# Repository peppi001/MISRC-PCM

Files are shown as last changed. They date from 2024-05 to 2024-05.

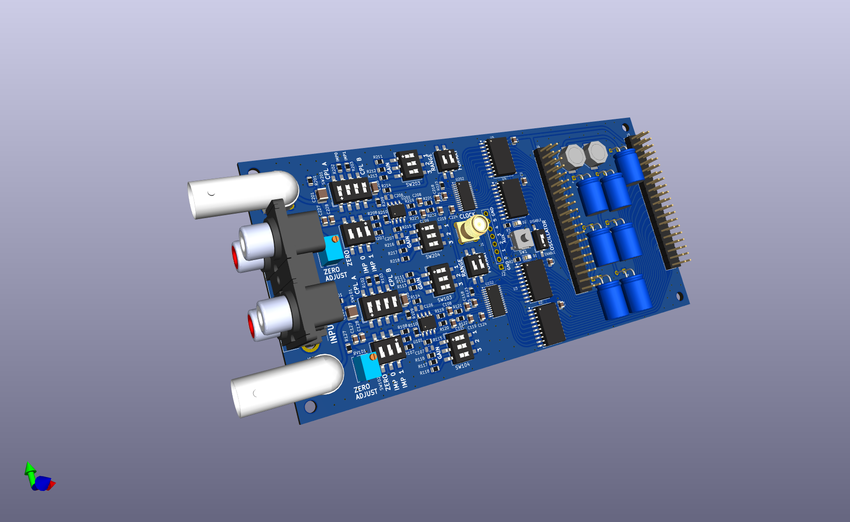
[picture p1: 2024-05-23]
3D_Pics/MISRC_v2.1_BNC_Top.png

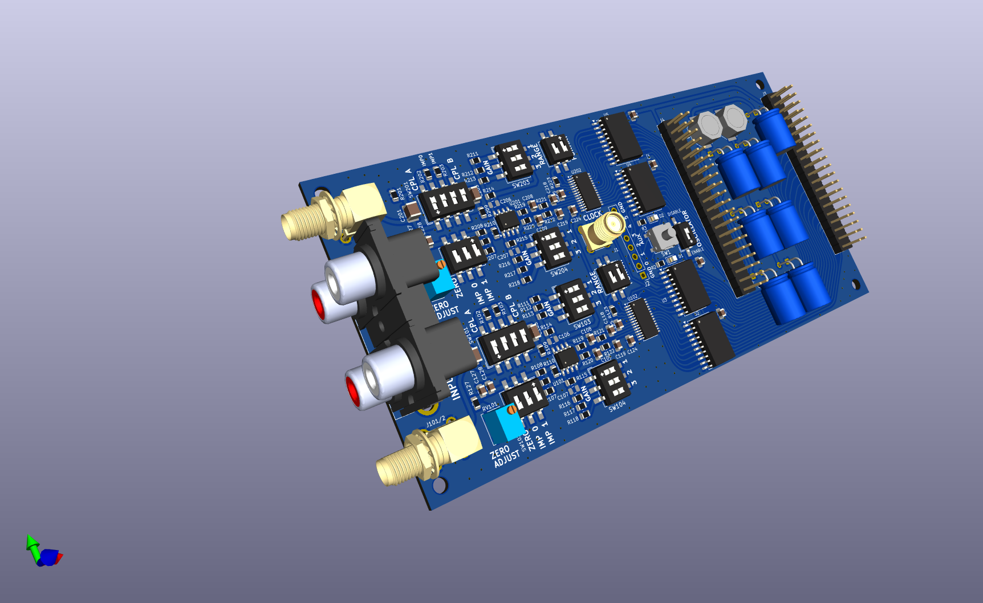
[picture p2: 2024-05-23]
3D_Pics/MISRC_v2.1_SMA_TOP.png

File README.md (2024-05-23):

# MISRC-PCM
SMA Version
MISRC_v2 1_SMA_TOP
MISRC_v2 1_SMA_BOT

BNC Version
MISRC_v2 1_BNC_Top
MISRC_v2 1_BNC_BOT

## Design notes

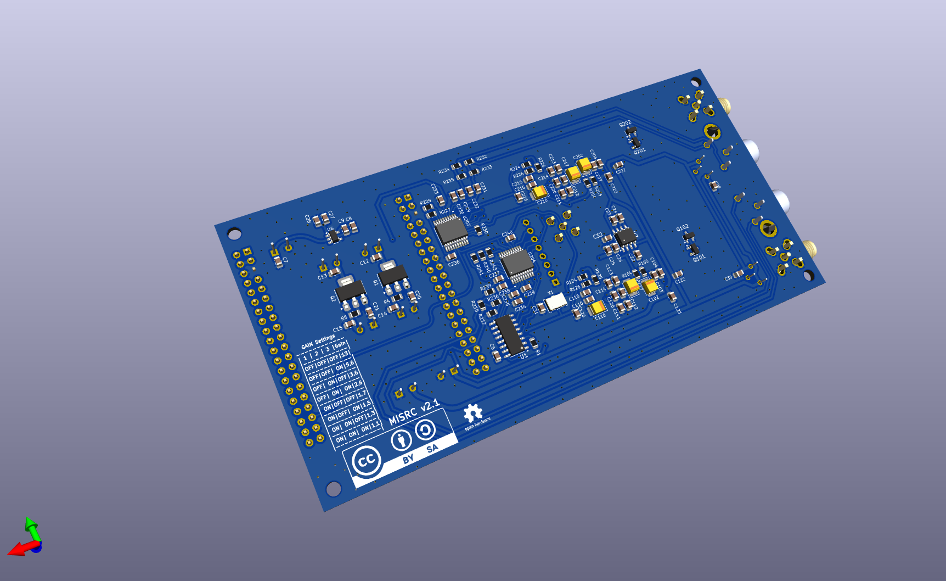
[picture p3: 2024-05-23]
3D_Pics/MISRC_v2.1_SMA_BOT.png

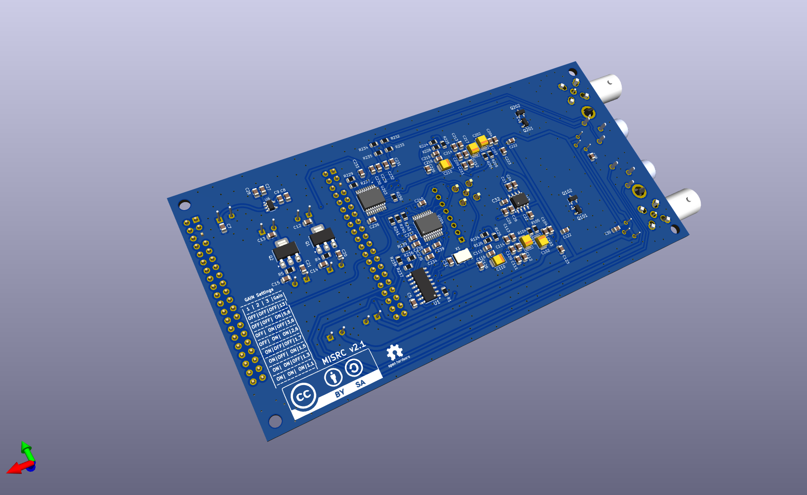
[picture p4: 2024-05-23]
3D_Pics/MISRC_v2.1_BNC_BOT.png

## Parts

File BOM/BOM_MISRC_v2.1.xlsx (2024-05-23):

Reference | Value | Footprint | Qty | DNP | Manufacturer_Part_Number
C1,C2,C3,C4,C5,C7,C12,C13,C20,C21,C22,C23,C24,C29,C30,C31,C231,C232,C237,C238 | 1u | Capacitor_SMD:C_0805_2012Metric | 20 |  | GRM219R61H105KA73D
C6,C10,C11,C16,C17,C18,C19 | 470u | CP_Radial_Flat_D8.0mm_P3.50mm | 7 |  | UHV1C471MPD
C8,C25,C28,C32,C127,C227,C229,C234 | 10u | Capacitor_SMD:C_0805_2012Metric | 8 |  | GRM21BR61C106KE15K
C9,C14,C15,C26,C103,C112,C113,C115,C120,C122,C123,C124,C125,C126,C203,C212,C213,C215,C220,C222,C223,C224,C225,C226,C230,C233,C235,C236,C239,C240 | 100n | Capacitor_SMD:C_0805_2012Metric | 30 |  | GRM21BR72A104KAC4L
C27,C104,C111,C114,C116,C121,C128,C204,C211,C214,C216,C221,C228 | 1n/1 | Capacitor_SMD:C_0805_2012Metric | 13 |  | GRM2195C1H102JA01D
C101,C201 | 100u | Capacitor_SMD:C_1210_3225Metric | 2 |  | GRM32ER61A107ME20K
C102,C110,C117,C202,C210,C217 | 10u | Capacitor_Tantalum_SMD:CP_EIA-3528-21_Kemet-B_Pad1.50x2.35mm_HandSolder | 6 |  | T491B106K016AT7280
C105,C205 | 470n/1 | Capacitor_SMD:C_1206_3216Metric | 2 |  | GRM31C5C1E474JE01L
~~C106,C107,C206,C207~~ | ~~1p~~ | ~~Capacitor_SMD:C_0805_2012Metric~~ | ~~4~~ | ~~DNP~~
C108,C109,C208,C209 | 82pF/1 | Capacitor_SMD:C_0805_2012Metric | 4 |  | GRM21A5C2D820JW01D
C118,C119,C218,C219 | 15pF/1 | Capacitor_SMD:C_0805_2012Metric | 4 |  | GRM21A5C2D150JW01D
D1,D2 | LED | LED_SMD:LED_0805_2012Metric_Pad1.15x1.40mm_HandSolder | 2 |  | APT2012EC
~~H1,H2,H3,H4~~ | ~~MountingHole~~ | ~~MountingHole:MountingHole_3.2mm_M3~~ | ~~4~~ | ~~DNP~~
J1 | Conn_01x01_Shielded | Footprints:SMA_Amphenol_901-144_Vertical2 | 1 |  | RF2-04A-T-00-50-G
~~J2~~ | ~~Conn_01x08_Socket~~ | ~~Connector_PinHeader_2.54mm:PinHeader_1x08_P2.54mm_Vertical~~ | ~~1~~ | ~~DNP~~ | ~~61300811121~~
J3 | GPIFII_J6 | Footprints:PinHeader_2x20_P2.54mm_Vertical-1 | 1 |  | 61302021121
J4 | GPIFII_J7 | Footprints:PinHeader_2x20_P2.54mm_Vertical-1 | 1 |  | 61302021121
~~J101,J201~~ | ~~BNC_Rosenberger~~ | ~~Footprints:BNC Socket_mod~~ | ~~2~~ | ~~DNP~~ | ~~DOSIN-801-0050~~
J101/2,J201/2 | Conn_01x01_Shielded | Footprints:SMA_Amphenol_901-144_Horizontal | 2 |  | CONSMA002-L-G
J202 | KLP42X-61-WW_RR | KLP42X61WWRR | 1 |  | KLP42X-61-WW/RR
L1,L2 | 100u | Footprints:L_Bourns-SRU8043_2 | 2 |  | SRU8043-101Y
Q1 | FZT690B | Package_TO_SOT_SMD:SOT-223-3_TabPin2 | 1 |  | FZT690BTA
Q2 | FZT790A | Package_TO_SOT_SMD:SOT-223-3_TabPin2 | 1 |  | FZT790A
Q101,Q102,Q201,Q202 | CMPT5179 | Package_TO_SOT_SMD:SOT-23 | 4 |  | CMPT5179 TR PBFREE
R1,R123,R126,R223,R226,R232,R234,R236,R238 | 10k | Resistor_SMD:R_0805_2012Metric | 9 |  | RC0805FR-0710KL
R2,R3 | 100 | Resistor_SMD:R_0805_2012Metric | 2 |  | RC0805FR-07100RL
R4,R5,R227,R229,R230,R240,R241,R243 | 1k | Resistor_SMD:R_0805_2012Metric | 8 |  | RT0805BRD071KL
R101,R103,R106,R201,R203,R206 | 75B | Resistor_SMD:R_0805_2012Metric | 6 |  | RT0805BRD0775RL
R102,R202 | 150B | Resistor_SMD:R_0805_2012Metric | 2 |  | RT0805BRD07150RL
R104,R105,R111,R116,R204,R205,R211,R216 | 1kB | Resistor_SMD:R_0805_2012Metric | 8 |  | RT0805BRD071KL
R107,R108,R207,R208 | 39B | Resistor_SMD:R_0805_2012Metric | 4 |  | RT0805BRD0739RL
R109,R110,R209,R210 | 499B | Resistor_SMD:R_0805_2012Metric | 4 |  | RT0805BRD07499RL
R112,R117,R212,R217 | 2k49B | Resistor_SMD:R_0805_2012Metric | 4 |  | RT0805BRD072K49L
R113,R118,R213,R218 | 4k99B | Resistor_SMD:R_0805_2012Metric | 4 |  | RT0805BRD074K99L
R114,R115,R214,R215 | 6k49B | Resistor_SMD:R_0805_2012Metric | 4 |  | RT0805BRD076K49L
R119,R120,R219,R220 | 40B | Resistor_SMD:R_0805_2012Metric | 4 |  | RT0805BRD0739R2L
R121,R122,R221,R222 | 22B | Resistor_SMD:R_0805_2012Metric | 4 |  | RT0805BRD0722RL
R124,R224 | 4k99 | Resistor_SMD:R_0805_2012Metric | 2 |  | RC0805FR-074K99L
R125,R127,R225,R228 | 3k3 | Resistor_SMD:R_0805_2012Metric | 4 |  | RC0805FR-073K3L
R233,R235,R237,R239 | 47k | Resistor_SMD:R_0805_2012Metric | 4 |  | RC0805FR-0747KL
RV101,RV201 | 10k | Potentiometer_THT:Potentiometer_Bourns_3266W_Vertical | 2 |  | 3266W-1-103LF
SW1 | SW_Push | Footprints:SW_SPST_EVQP0_2 | 1 |  | B3FS-1010P
SW2 | SW_DIP_x01 | Button_Switch_SMD:SW_DIP_SPSTx01_Slide_6.7x4.1mm_W8.61mm_P2.54mm_LowProfile | 1 |  | EDS01SGRSTR04Q
SW101,SW201 | SW_DIP_x04 | Button_Switch_SMD:SW_DIP_SPSTx04_Slide_6.7x11.72mm_W8.61mm_P2.54mm_LowProfile | 2 |  | IKD0403101
SW102,SW103,SW104,SW202,SW203,SW204 | SW_DIP_x03 | Button_Switch_SMD:SW_DIP_SPSTx03_Slide_6.7x9.18mm_W8.61mm_P2.54mm_LowProfile | 6 |  | A6S-3104-H
SW105,SW205 | SW_DIP_x02 | Button_Switch_SMD:SW_DIP_SPSTx02_Slide_6.7x6.64mm_W8.61mm_P2.54mm_LowProfile | 2 |  | IKD0203101
U1 | 4043 | Package_SO:SO-16_3.9x9.9mm_P1.27mm | 1 |  | HEF4043BT-Q100J
U2,U3,U4,U5 | 74VHC541 | Package_SO:SOIC-20W_7.5x12.8mm_P1.27mm | 4 |  | 74VHC541D,118
U6 | TPS60401 | Package_TO_SOT_SMD:SOT-23-5 | 1 |  | TPS60401DBVT
U7 | ADP7156ARDZ | Footprints:SOIC-8-1EP_3.9x4.9mm_P1.27mm_EP2.29x3mm_2 | 1 |  | ADP7156ARDZ-3.3-R7
U101,U201 | AD8138ARZ | Package_SO:SO-8_3.9x4.9mm_P1.27mm | 2 |  | AD8138ARZ
U102,U202 | AD9235 | Package_SO:TSSOP-28_4.4x9.7mm_P0.65mm | 2 |  | AD9235BRUZ-40
U203,U204 | PCM1802DBR | Footprints:SOP65P780X200-20N | 2 |  | PCM1802DBR
X1 | 40M | Oscillator:Oscillator_SMD_EuroQuartz_XO53-4Pin_5.0x3.2mm | 1 |  | ECS-5032MV-400-CN-TR

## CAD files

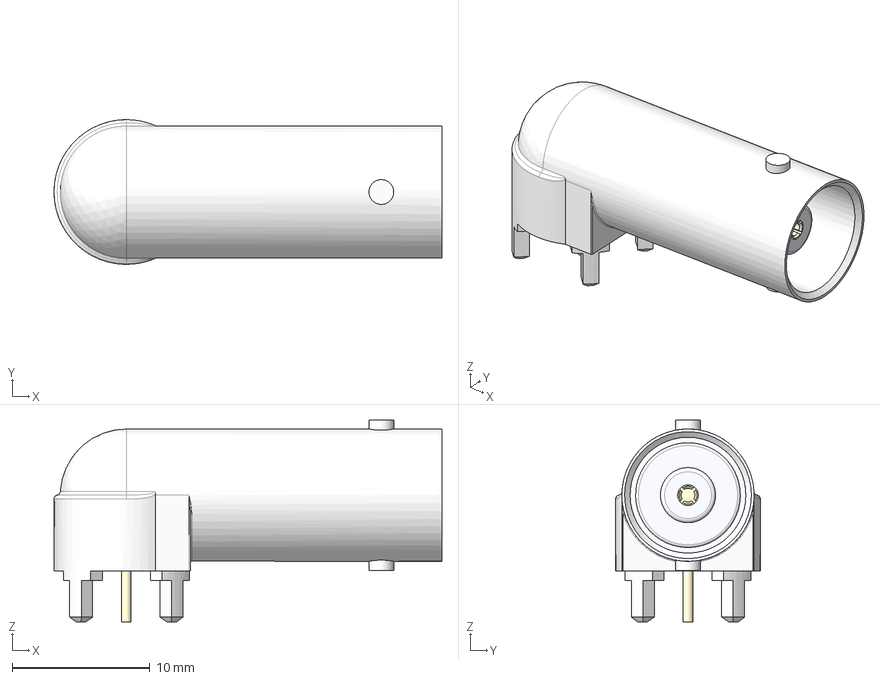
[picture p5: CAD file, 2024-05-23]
3d_models/DOSIN-BNC_F102-243.stp
28.1 x 10.5 x 14.7 mm

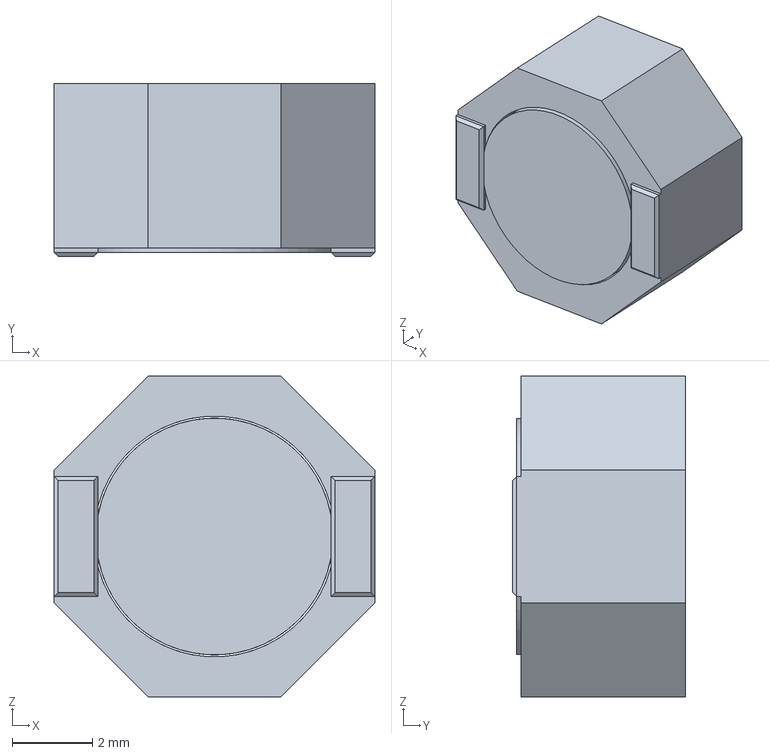
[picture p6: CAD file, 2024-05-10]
3d_models/sru8043-101y.stp
8.00 x 4.30 x 8.00 mm

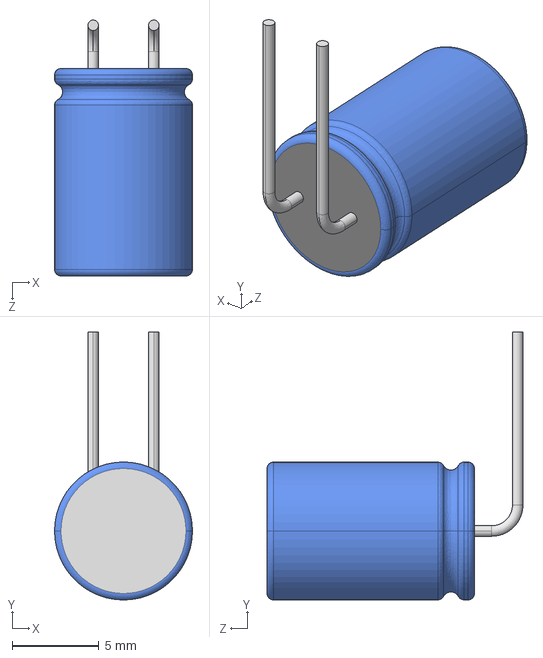
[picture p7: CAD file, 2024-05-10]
3d_models/User Library-cap_pol8x12_RA.STEP
7.98 x 15.5 x 14.8 mm

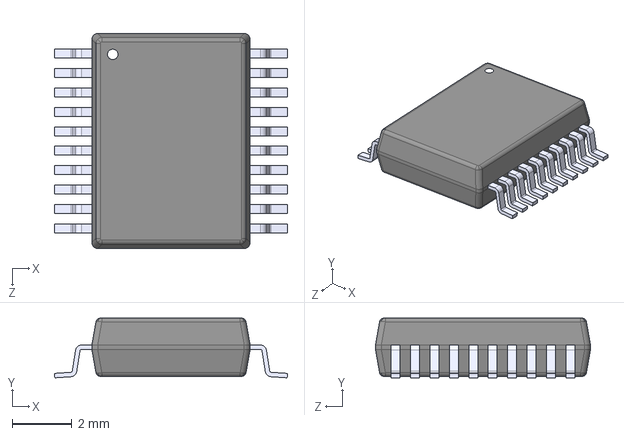
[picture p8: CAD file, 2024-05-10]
3d_models/PCM1802DBR.step
7.80 x 2.00 x 7.20 mm

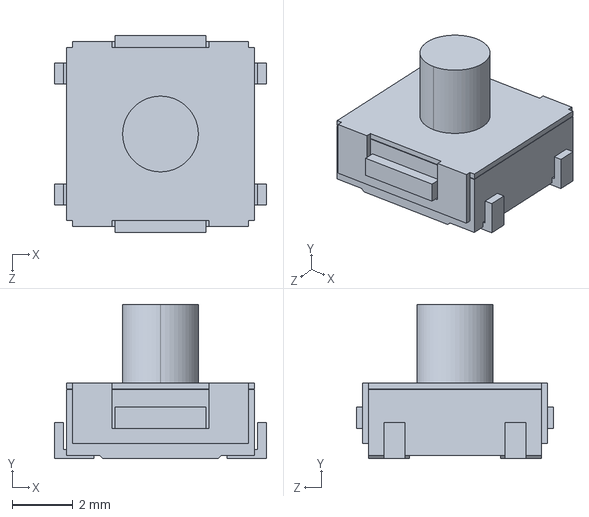
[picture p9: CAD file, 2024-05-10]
3d_models/B3SL-1022P.step
7.00 x 5.10 x 6.50 mm

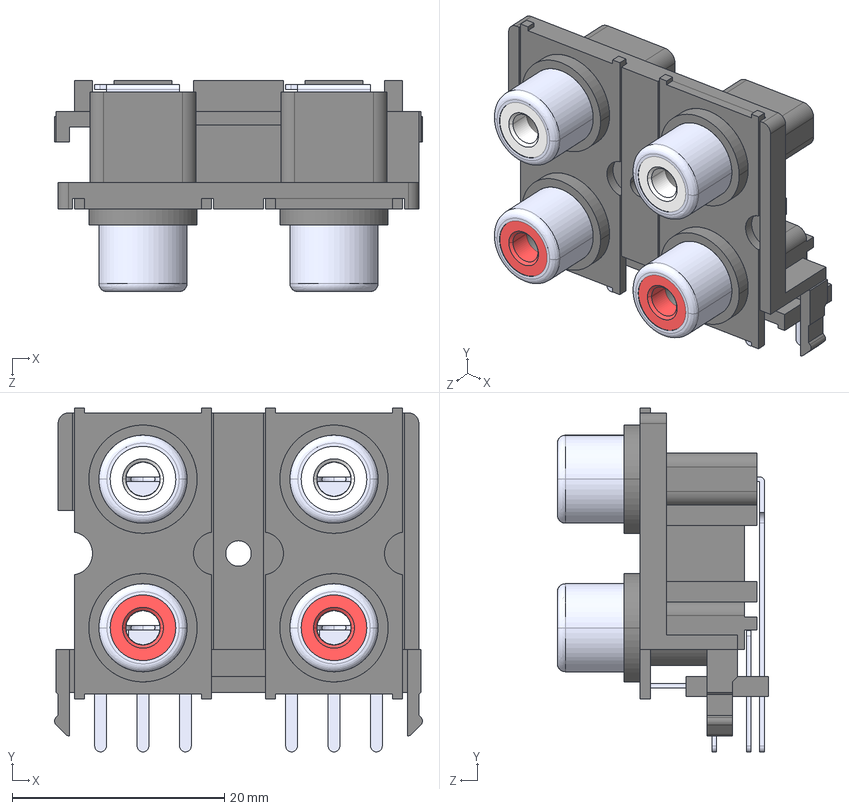
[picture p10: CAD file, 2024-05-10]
3d_models/KLP42X-61-WW-RR_rA7.IGS
34.7 x 32.4 x 19.9 mm

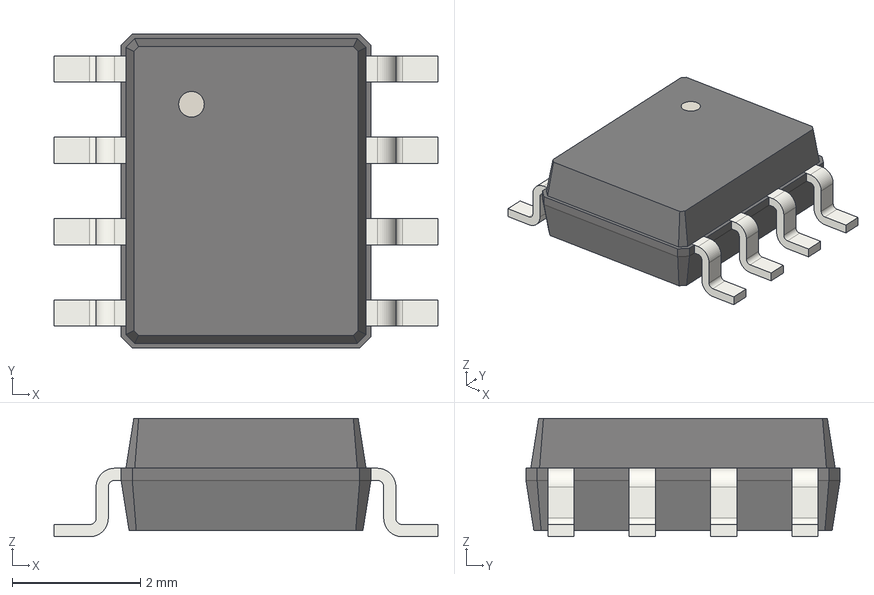
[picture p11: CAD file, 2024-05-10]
3d_models/SO-8_3.9x4.9mm_P1.27mm.step
6.00 x 4.91 x 1.85 mm
729b06ae-9266-11ed-9e62-a0cec80452fd_part
729b0bae-9266-11ed-9e62-a0cec80452fd_part
729b0e92-9266-11ed-9e62-a0cec80452fd_part
729b1108-9266-11ed-9e62-a0cec80452fd_part

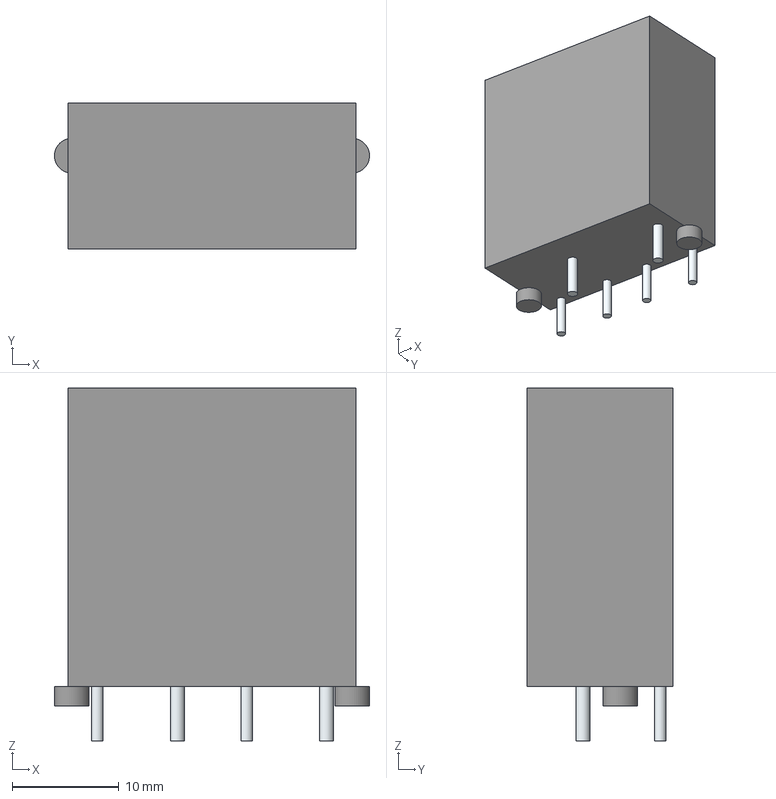
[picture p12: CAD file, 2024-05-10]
3d_models/PJRAS2X2S01X.stp
29.5 x 13.7 x 33.1 mm
Lugs x 8
Leads x 8

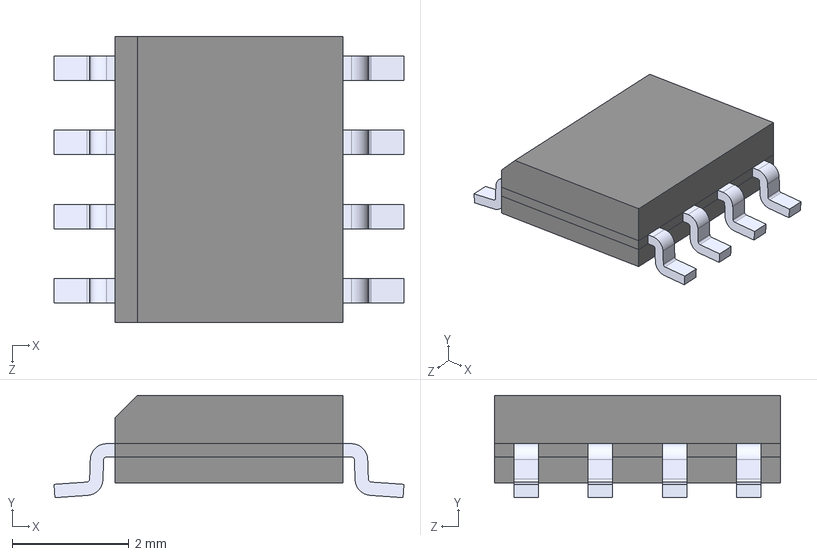
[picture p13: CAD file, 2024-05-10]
3d_models/ADP7156ARDZ-3.3-R7.STEP
5.99 x 1.75 x 4.90 mm

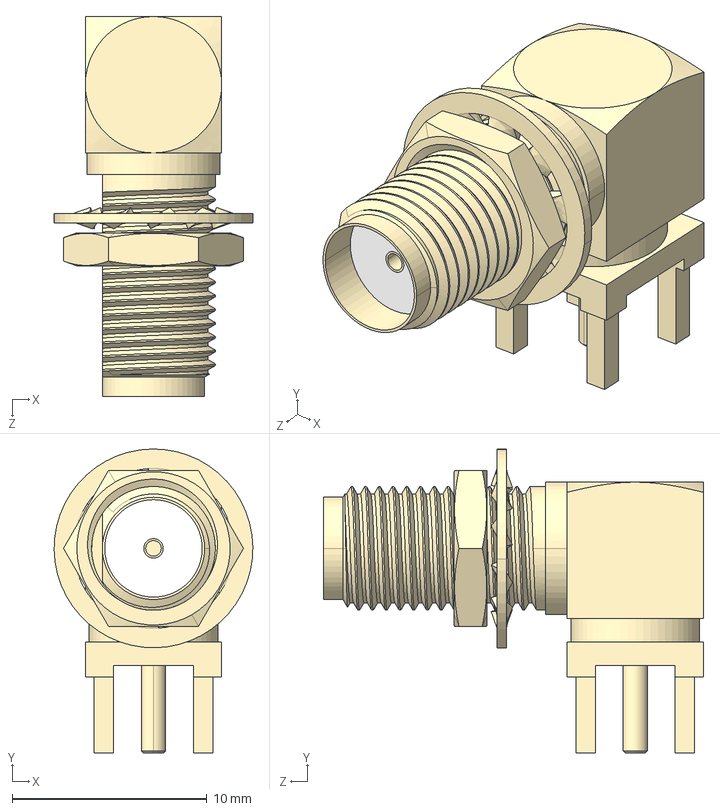
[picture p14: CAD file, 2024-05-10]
3d_models/CONSMA002-L-G.step
10.2 x 15.6 x 19.5 mm
CONSMA002-L-G-body
Nut
Washer

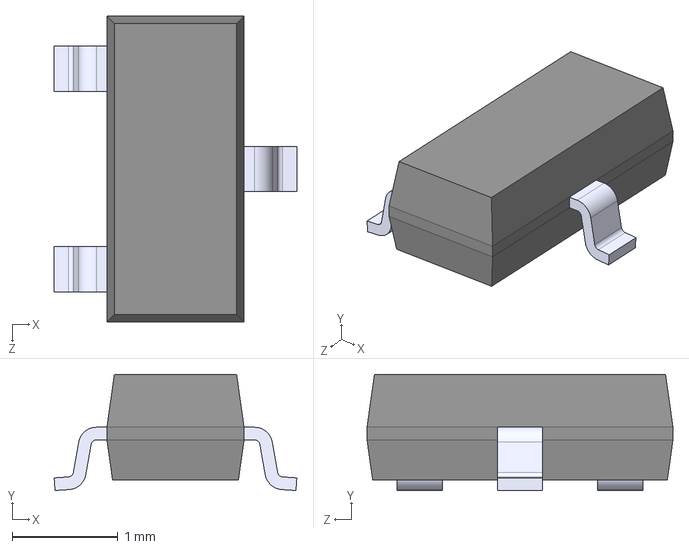
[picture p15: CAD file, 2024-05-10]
3d_models/PESD5V0U2BT_215.step
2.30 x 1.10 x 2.90 mm

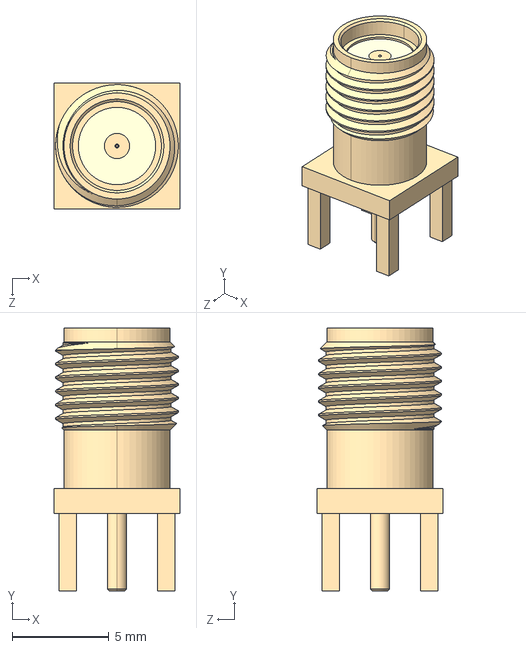
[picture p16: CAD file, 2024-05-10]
3d_models/SMA_CONNECTOR.step
6.50 x 13.6 x 6.50 mm

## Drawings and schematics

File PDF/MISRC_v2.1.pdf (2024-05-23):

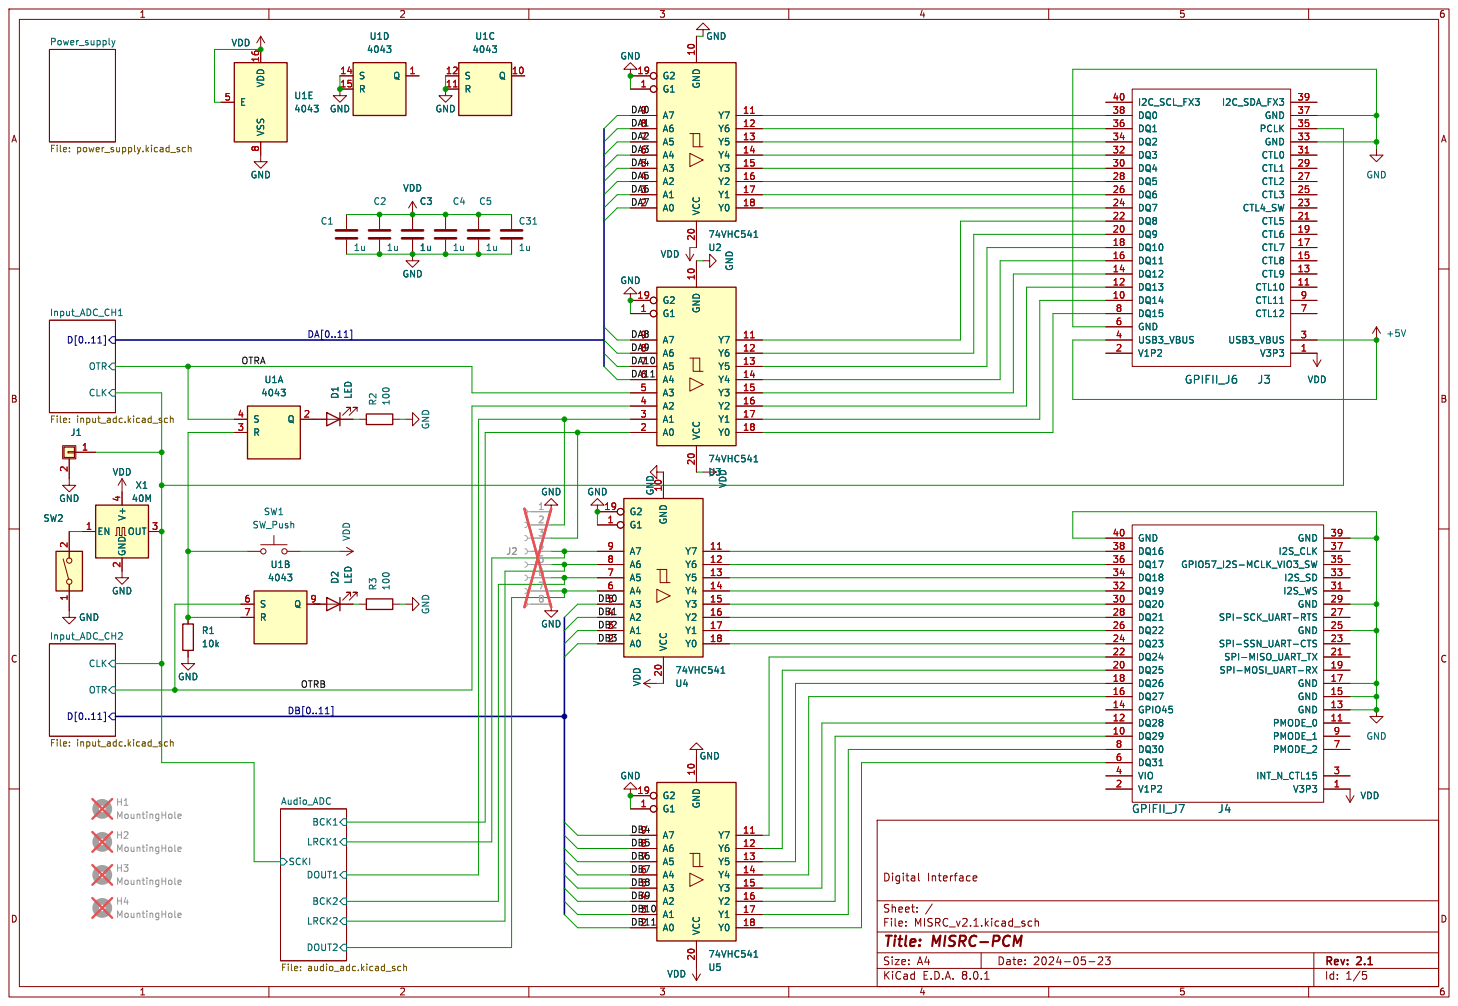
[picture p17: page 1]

File: MISRC_v2.1.kicad_sch Sheet: / Digital Interface

Id: 1/5 Title: MISRC-PCM

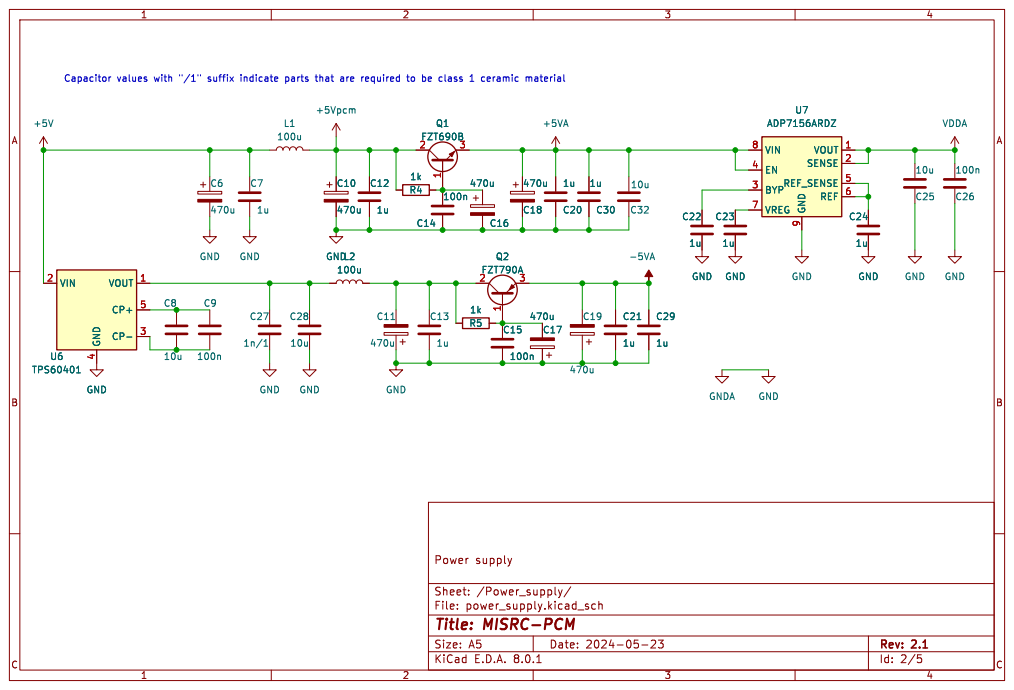
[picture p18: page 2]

Id: 2/5 Title: MISRC-PCM

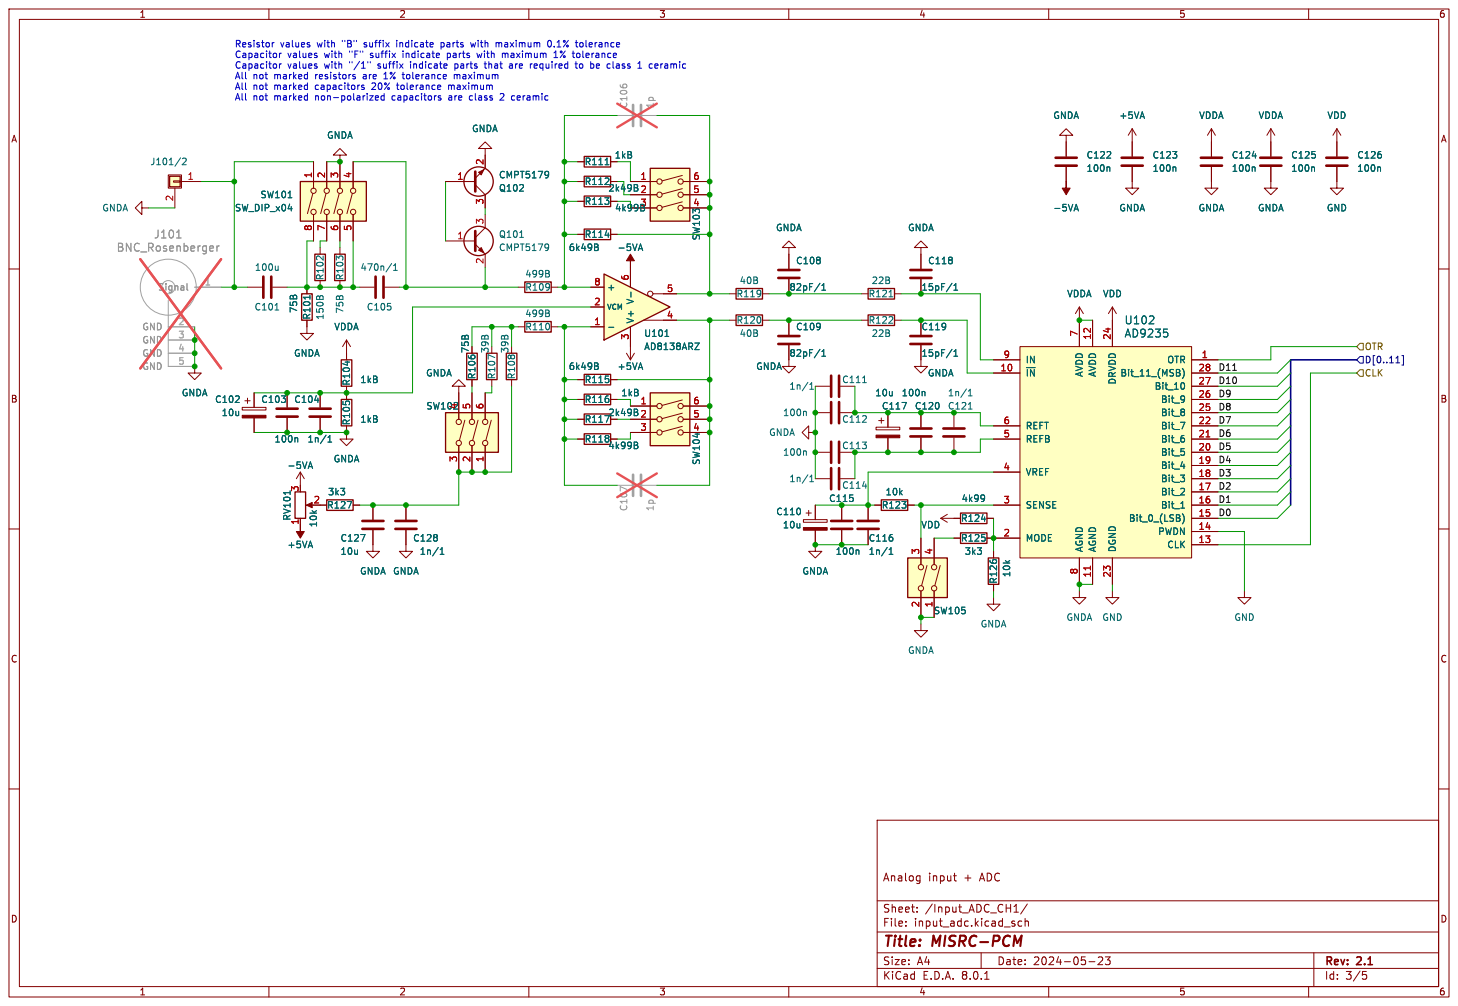
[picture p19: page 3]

File: input_adc.kicad_sch Sheet: /Input_ADC_CH1/
Id: 3/5 Title: MISRC-PCM

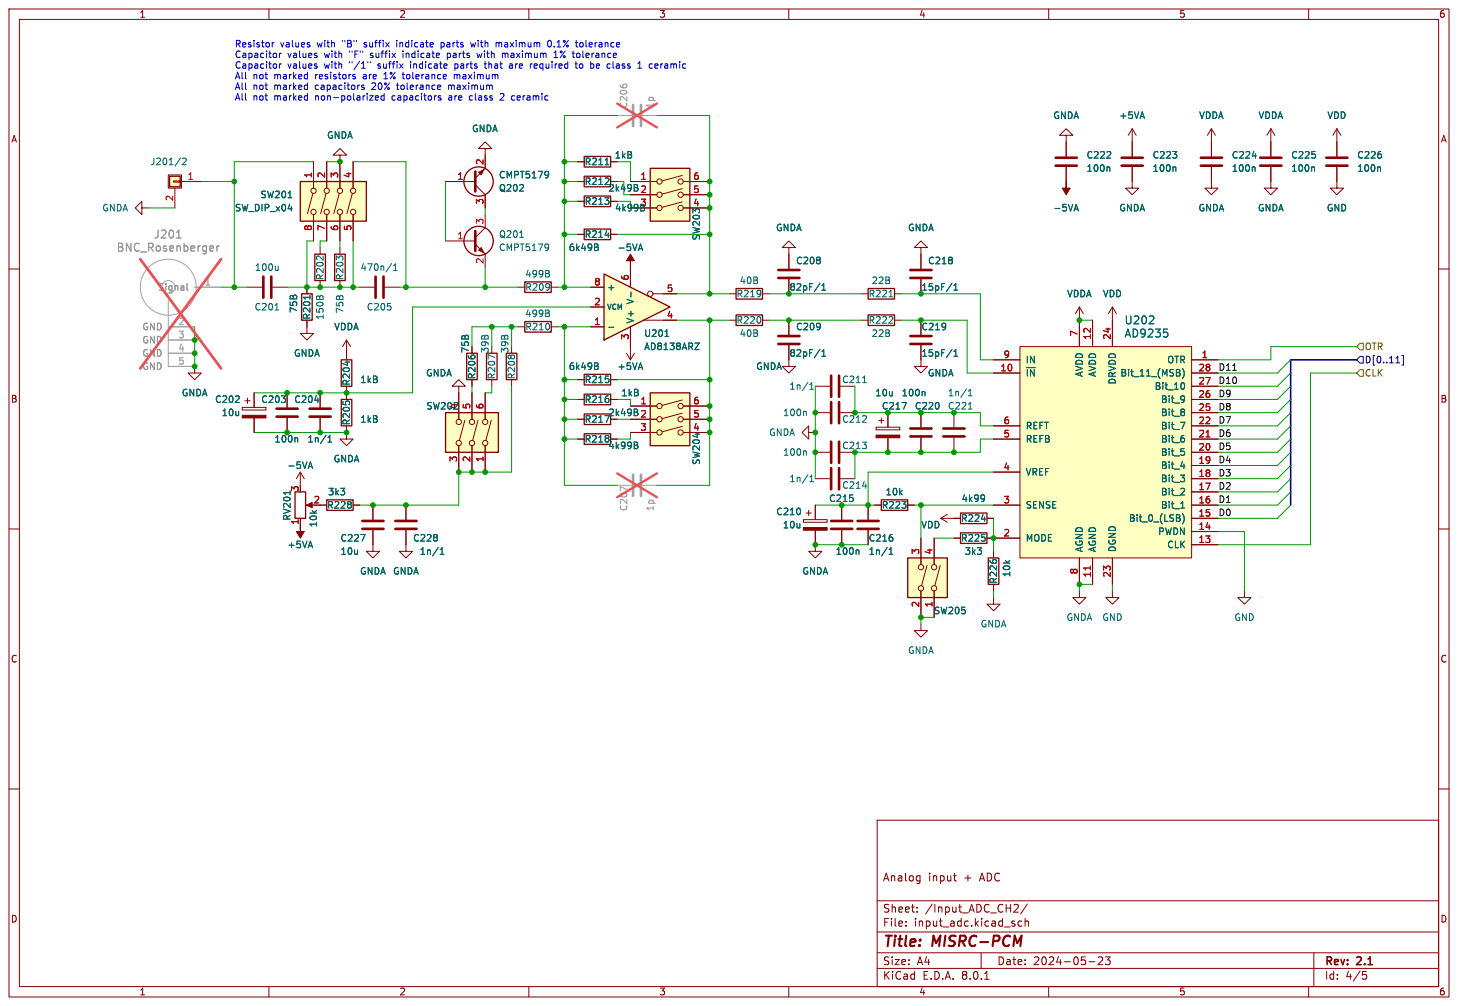
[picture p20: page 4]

File: input_adc.kicad_sch Sheet: /Input_ADC_CH2/
Id: 4/5 Title: MISRC-PCM

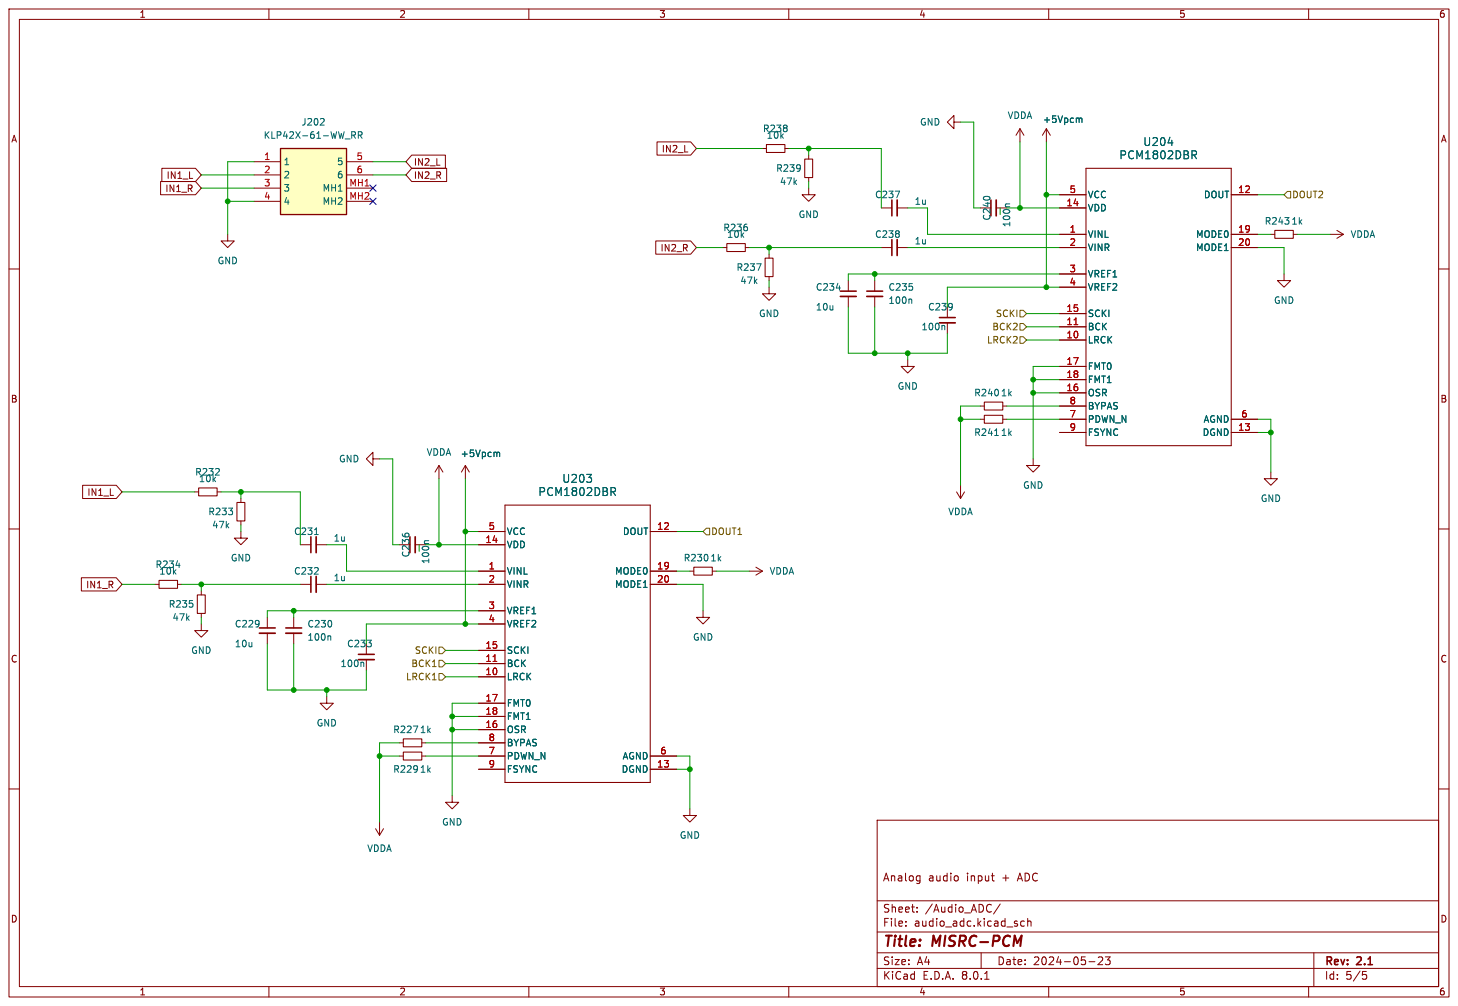
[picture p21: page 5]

Analog audio input + ADC

File: audio_adc.kicad_sch Sheet: /Audio_ADC/
Id: 5/5 Title: MISRC-PCM

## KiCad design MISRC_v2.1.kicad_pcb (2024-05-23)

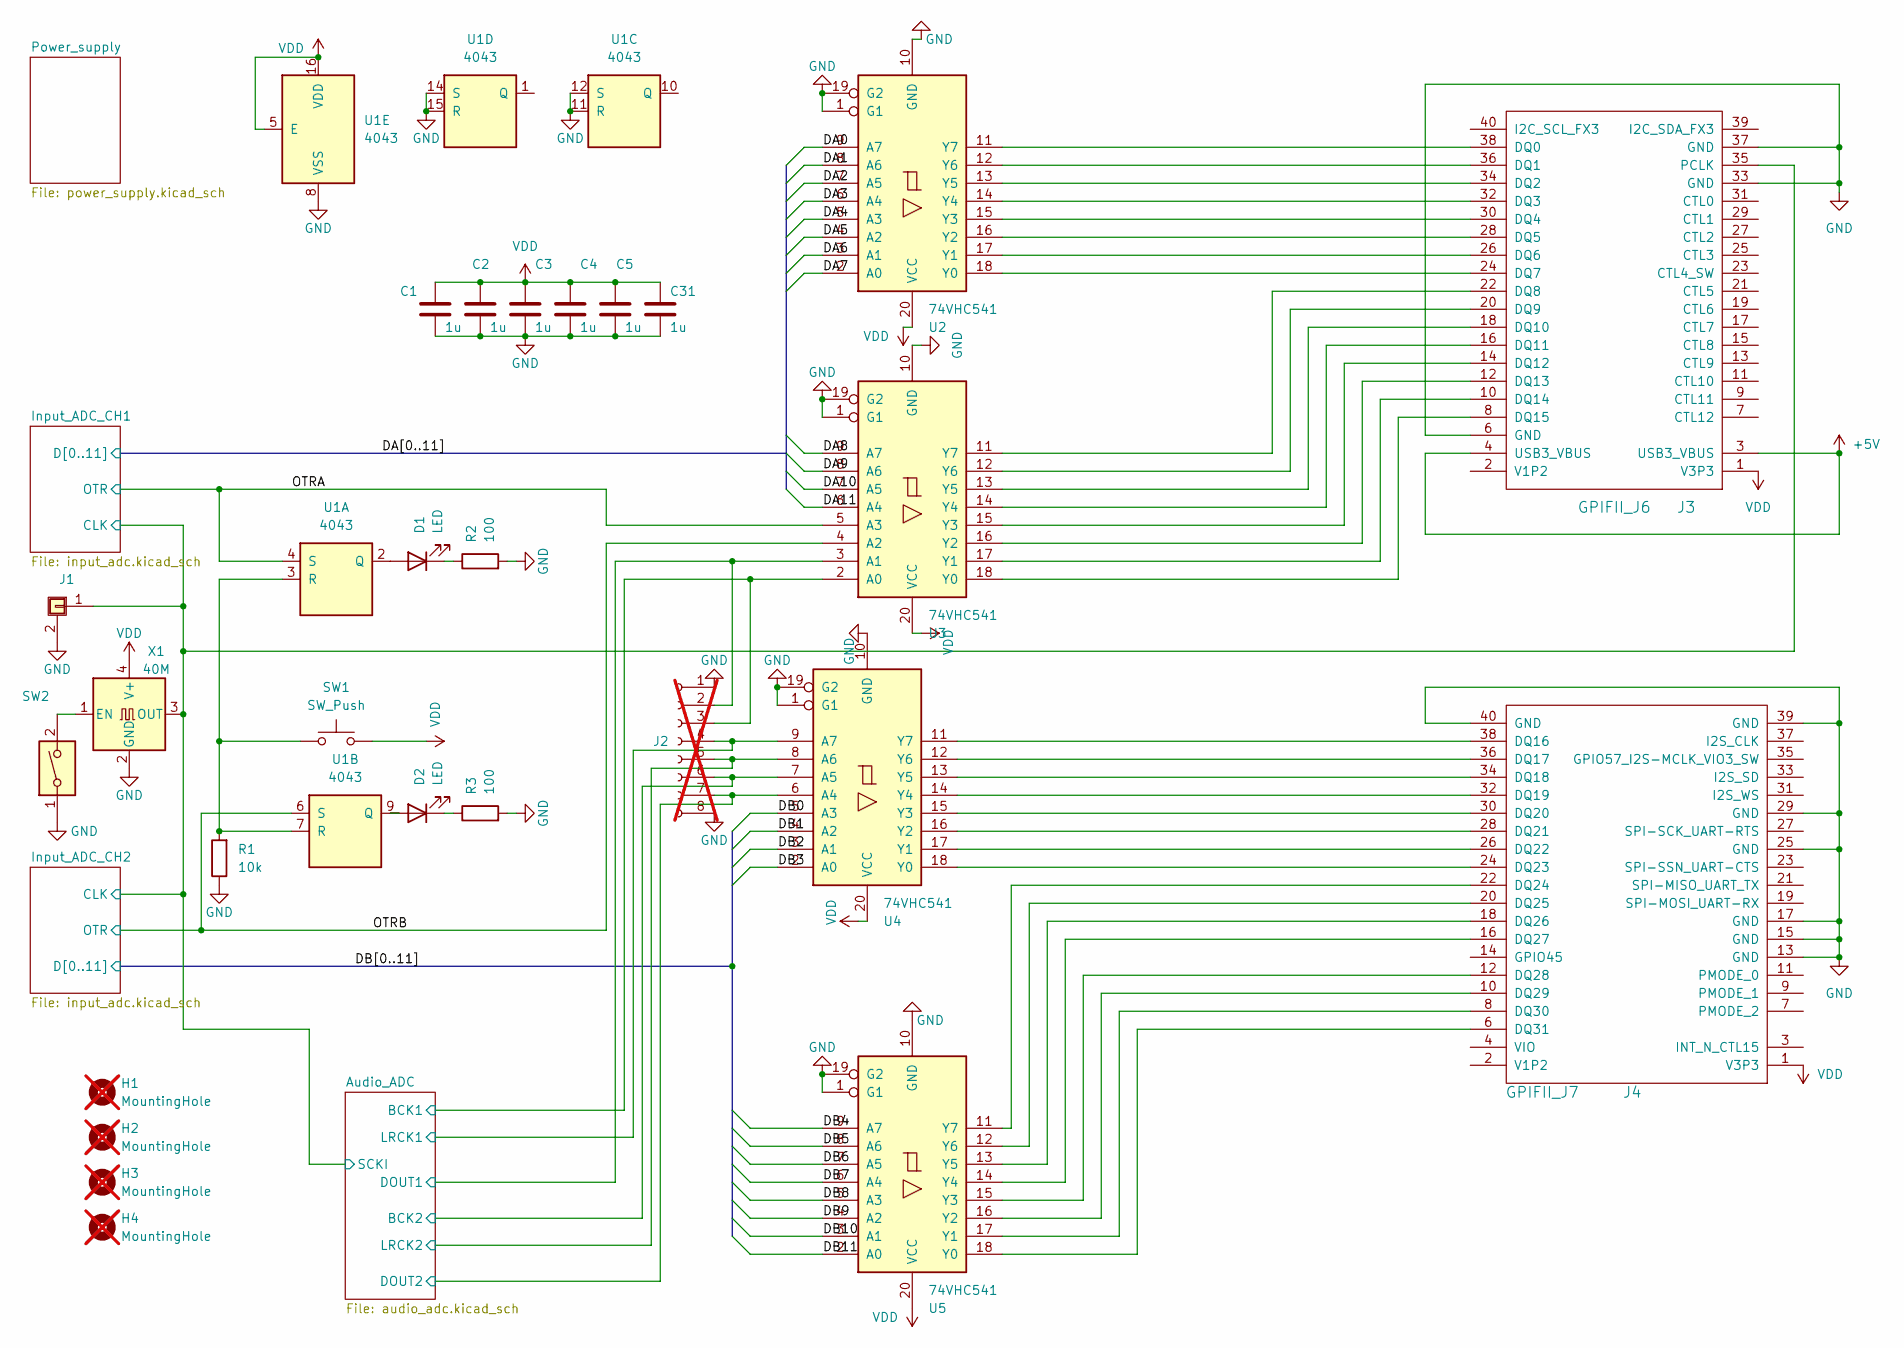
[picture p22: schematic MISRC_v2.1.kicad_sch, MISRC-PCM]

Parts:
C1, C2, C3, C4, C5, C31: 1u; C_0805_2012Metric; Manufacturer_Part_Number GRM219R61H105KA73D
D1, D2: LED; LED_0805_2012Metric_Pad1.15x1.40mm_HandSolder; Manufacturer_Part_Number APT2012EC
H1, H2, H3, H4: MountingHole; MountingHole_3.2mm_M3; not fitted
J1: Conn_01x01_Shielded; SMA_Amphenol_901-144_Vertical2; Manufacturer_Part_Number RF2-04A-T-00-50-G
J2: Conn_01x08_Socket; PinHeader_1x08_P2.54mm_Vertical; Manufacturer_Part_Number 61300811121; not fitted
J3: GPIFII_J6; PinHeader_2x20_P2.54mm_Vertical-1; Manufacturer_Part_Number 61302021121
J4: GPIFII_J7; PinHeader_2x20_P2.54mm_Vertical-1; Manufacturer_Part_Number 61302021121
R1: 10k; R_0805_2012Metric; Manufacturer_Part_Number RC0805FR-0710KL
R2, R3: 100; R_0805_2012Metric; Manufacturer_Part_Number RC0805FR-07100RL
SW1: SW_Push; SW_SPST_EVQP0_2; Manufacturer_Part_Number B3FS-1010P
SW2: SW_DIP_x01; SW_DIP_SPSTx01_Slide_6.7x4.1mm_W8.61mm_P2.54mm_LowProfile; Manufacturer_Part_Number EDS01SGRSTR04Q
U1: 4043; SO-16_3.9x9.9mm_P1.27mm; Manufacturer_Part_Number HEF4043BT-Q100J
U2, U3, U4, U5: 74VHC541; SOIC-20W_7.5x12.8mm_P1.27mm; Manufacturer_Part_Number 74VHC541D,118
X1: 40M; Oscillator_SMD_EuroQuartz_XO53-4Pin_5.0x3.2mm; Manufacturer_Part_Number ECS-5032MV-400-CN-TR

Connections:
+5V: J3.3 (USB3_VBUS), J3.4 (USB3_VBUS); also elsewhere on the board
/Audio_ADC/BCK1: J2.3, U3.2 (A0); also elsewhere on the board
/Audio_ADC/BCK2: J2.6, U4.7 (A5); also elsewhere on the board
/Audio_ADC/DOUT1: J2.2, U3.3 (A1); also elsewhere on the board
/Audio_ADC/DOUT2: J2.7, U4.6 (A4); also elsewhere on the board
/Audio_ADC/LRCK1: J2.4, U4.9 (A7); also elsewhere on the board
/Audio_ADC/LRCK2: J2.5, U4.8 (A6); also elsewhere on the board
/Audio_ADC/SCKI: J1.1, J3.35 (PCLK), X1.3 (OUT); also elsewhere on the board
/DA0: U2.9 (A7); also elsewhere on the board
/DA1: U2.8 (A6); also elsewhere on the board
/DA2: U2.7 (A5); also elsewhere on the board
/DA3: U2.6 (A4); also elsewhere on the board
/DA4: U2.5 (A3); also elsewhere on the board
/DA5: U2.4 (A2); also elsewhere on the board
/DA6: U2.3 (A1); also elsewhere on the board
/DA7: U2.2 (A0); also elsewhere on the board
/DA8: U3.9 (A7); also elsewhere on the board
/DA9: U3.8 (A6); also elsewhere on the board
/DA10: U3.7 (A5); also elsewhere on the board
/DA11: U3.6 (A4); also elsewhere on the board
/DB0: U4.5 (A3); also elsewhere on the board
/DB1: U4.4 (A2); also elsewhere on the board
/DB2: U4.3 (A1); also elsewhere on the board
/DB3: U4.2 (A0); also elsewhere on the board
/DB4: U5.9 (A7); also elsewhere on the board
/DB5: U5.8 (A6); also elsewhere on the board
/DB6: U5.7 (A5); also elsewhere on the board
/DB7: U5.6 (A4); also elsewhere on the board
/DB8: U5.5 (A3); also elsewhere on the board
/DB9: U5.4 (A2); also elsewhere on the board
/DB10: U5.3 (A1); also elsewhere on the board
/DB11: U5.2 (A0); also elsewhere on the board
/OTRA: U1.4 (S), U3.5 (A3); also elsewhere on the board
/OTRB: U1.6 (S), U3.4 (A2); also elsewhere on the board
GND: C1.2, C2.2, C3.2, C4.2, C5.2, C31.2, J1.2 (Shield), J2.1, J2.8, J3.6 (GND), J3.33 (GND), J3.37 (GND), J4.13 (GND), J4.15 (GND), J4.17 (GND), J4.25 (GND), J4.29 (GND), J4.39 (GND), J4.40 (GND), R1.1, R2.2, R3.2, SW2.1, U1.8 (VSS), U1.11 (R), U1.12 (S), U1.14 (S), U1.15 (R), U2.1 (G1), U2.10 (GND), U2.19 (G2), U3.1 (G1), U3.10 (GND), U3.19 (G2), U4.1 (G1), U4.10 (GND), U4.19 (G2), U5.1 (G1), U5.10 (GND), U5.19 (G2), X1.2 (GND); also elsewhere on the board
unnamed: D1.2 (A), U1.2 (Q)
unnamed: D1.1 (K), R2.1
unnamed: D2.2 (A), U1.9 (Q)
unnamed: D2.1 (K), R3.1
unnamed: J3.38 (DQ0), U2.11 (Y7)
unnamed: J3.36 (DQ1), U2.12 (Y6)
unnamed: J3.34 (DQ2), U2.13 (Y5)
unnamed: J3.32 (DQ3), U2.14 (Y4)
unnamed: J3.30 (DQ4), U2.15 (Y3)
unnamed: J3.28 (DQ5), U2.16 (Y2)
unnamed: J3.26 (DQ6), U2.17 (Y1)
unnamed: J3.24 (DQ7), U2.18 (Y0)
unnamed: J3.22 (DQ8), U3.11 (Y7)
unnamed: J3.20 (DQ9), U3.12 (Y6)
unnamed: J3.18 (DQ10), U3.13 (Y5)
unnamed: J3.16 (DQ11), U3.14 (Y4)
unnamed: J3.14 (DQ12), U3.15 (Y3)
unnamed: J3.12 (DQ13), U3.16 (Y2)
unnamed: J3.10 (DQ14), U3.17 (Y1)
unnamed: J3.8 (DQ15), U3.18 (Y0)
unnamed: J4.38 (DQ16), U4.11 (Y7)
unnamed: J4.36 (DQ17), U4.12 (Y6)
unnamed: J4.34 (DQ18), U4.13 (Y5)
unnamed: J4.32 (DQ19), U4.14 (Y4)
unnamed: J4.30 (DQ20), U4.15 (Y3)
unnamed: J4.28 (DQ21), U4.16 (Y2)
unnamed: J4.26 (DQ22), U4.17 (Y1)
unnamed: J4.24 (DQ23), U4.18 (Y0)
unnamed: J4.22 (DQ24), U5.11 (Y7)
unnamed: J4.20 (DQ25), U5.12 (Y6)
unnamed: J4.18 (DQ26), U5.13 (Y5)
unnamed: J4.16 (DQ27), U5.14 (Y4)
unnamed: J4.12 (DQ28), U5.15 (Y3)
unnamed: J4.10 (DQ29), U5.16 (Y2)
unnamed: J4.8 (DQ30), U5.17 (Y1)
unnamed: J4.6 (DQ31), U5.18 (Y0)
unnamed: R1.2, SW1.1, U1.3 (R), U1.7 (R)
unnamed: SW2.2, X1.1 (EN)
VDD: C1.1, C2.1, C3.1, C4.1, C5.1, C31.1, J3.1 (V3P3), J4.1 (V3P3), SW1.2, U1.5 (E), U1.16 (VDD), U2.20 (VCC), U3.20 (VCC), U4.20 (VCC), U5.20 (VCC), X1.4 (V+); also elsewhere on the board

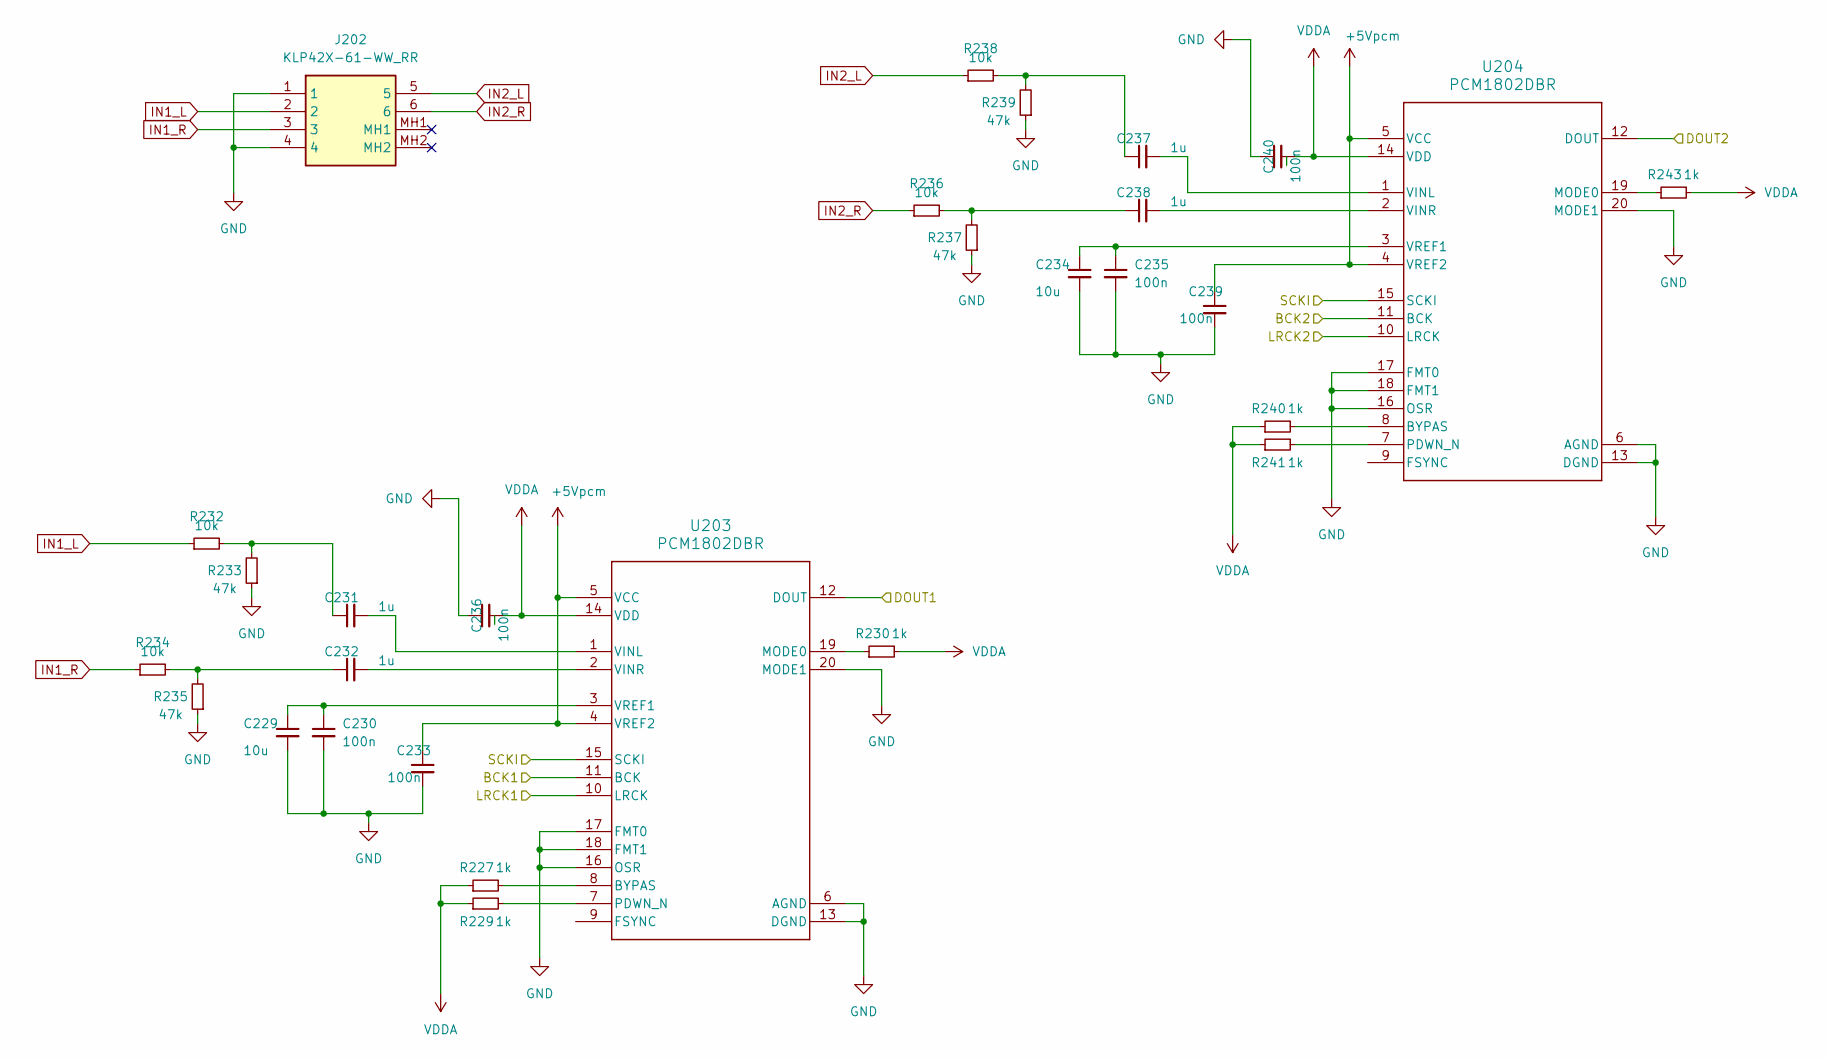
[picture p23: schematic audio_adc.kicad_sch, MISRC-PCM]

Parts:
C229, C234: 10u; C_0805_2012Metric; Manufacturer_Part_Number GRM21BR61C106KE15K
C230, C233, C235, C236, C239, C240: 100n; C_0805_2012Metric; Manufacturer_Part_Number GRM21BR72A104KAC4L
C231, C232, C237, C238: 1u; C_0805_2012Metric; Manufacturer_Part_Number GRM219R61H105KA73D
J202: KLP42X-61-WW_RR; KLP42X61WWRR; Mouser Part Number 806-KLP42X-61-WWRR
R227, R229, R230, R240, R241, R243: 1k; R_0805_2012Metric; Manufacturer_Part_Number RT0805BRD071KL
R232, R234, R236, R238: 10k; R_0805_2012Metric; Manufacturer_Part_Number RC0805FR-0710KL
R233, R235, R237, R239: 47k; R_0805_2012Metric; Manufacturer_Part_Number RC0805FR-0747KL
U203, U204: PCM1802DBR; SOP65P780X200-20N; Manufacturer_Part_Number PCM1802DBR

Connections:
+5Vpcm: C233.1, C239.1, U203.4 (VREF2), U203.5 (VCC), U204.4 (VREF2), U204.5 (VCC); also elsewhere on the board
/Audio_ADC/BCK1: U203.11 (BCK); also elsewhere on the board
/Audio_ADC/BCK2: U204.11 (BCK); also elsewhere on the board
/Audio_ADC/DOUT1: U203.12 (DOUT); also elsewhere on the board
/Audio_ADC/DOUT2: U204.12 (DOUT); also elsewhere on the board
/Audio_ADC/LRCK1: U203.10 (LRCK); also elsewhere on the board
/Audio_ADC/LRCK2: U204.10 (LRCK); also elsewhere on the board
/Audio_ADC/SCKI: U203.15 (SCKI), U204.15 (SCKI); also elsewhere on the board
GND: C229.2, C230.2, C233.2, C234.2, C235.2, C236.1, C239.2, C240.1, J202.1, J202.4, R233.1, R235.1, R237.1, R239.1, U203.6 (AGND), U203.13 (DGND), U203.16 (OSR), U203.17 (FMT0), U203.18 (FMT1), U203.20 (MODE1), U204.6 (AGND), U204.13 (DGND), U204.16 (OSR), U204.17 (FMT0), U204.18 (FMT1), U204.20 (MODE1); also elsewhere on the board
IN1_L: J202.2, R232.1
IN1_R: J202.3, R234.1
IN2_L: J202.5, R238.1
IN2_R: J202.6, R236.1
unnamed: C231.1, R232.2, R233.2
unnamed: C232.1, R234.2, R235.2
unnamed: C237.1, R238.2, R239.2
unnamed: C238.1, R236.2, R237.2
unnamed: R227.2, U203.8 (BYPAS)
unnamed: R230.1, U203.19 (MODE0)
unnamed: R229.2, U203.7 (PDWN_N)
unnamed: C231.2, U203.1 (VINL)
unnamed: C232.2, U203.2 (VINR)
unnamed: C229.1, C230.1, U203.3 (VREF1)
unnamed: R240.2, U204.8 (BYPAS)
unnamed: R243.1, U204.19 (MODE0)
unnamed: R241.2, U204.7 (PDWN_N)
unnamed: C237.2, U204.1 (VINL)
unnamed: C238.2, U204.2 (VINR)
unnamed: C234.1, C235.1, U204.3 (VREF1)
VDDA: C236.2, C240.2, R227.1, R229.1, R230.2, R240.1, R241.1, R243.2, U203.14 (VDD), U204.14 (VDD); also elsewhere on the board

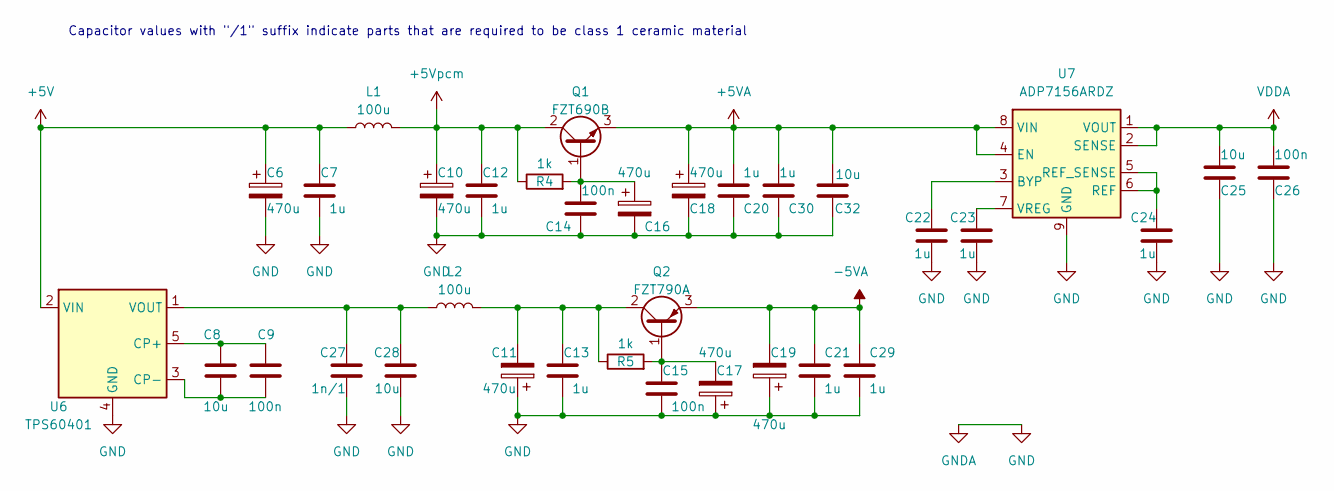
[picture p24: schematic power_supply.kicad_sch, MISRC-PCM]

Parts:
C6, C16, C19: 470u; CP_Radial_FlatB_D8.0mm_P3.50mm_3; Manufacturer_Part_Number UHV1C471MPD
C7, C12, C13, C20, C21, C22, C23, C24, C29, C30: 1u; C_0805_2012Metric; Manufacturer_Part_Number GRM219R61H105KA73D
C8, C25, C28, C32: 10u; C_0805_2012Metric; Manufacturer_Part_Number GRM21BR61C106KE15K
C9, C14, C15, C26: 100n; C_0805_2012Metric; Manufacturer_Part_Number GRM21BR72A104KAC4L
C10, C17, C18: 470u; CP_Radial_Flat_D8.0mm_P3.50mm_2; Manufacturer_Part_Number UHV1C471MPD
C11: 470u; CP_Radial_FlatB_D8.0mm_P3.50mm_2; Manufacturer_Part_Number UHV1C471MPD
C27: 1n/1; C_0805_2012Metric; Manufacturer_Part_Number GRM2195C1H102JA01D
L1, L2: 100u; L_Bourns-SRU8043_2; Manufacturer_Part_Number SRU8043-101Y
Q1: FZT690B; SOT-223-3_TabPin2; Manufacturer_Part_Number FZT690BTA
Q2: FZT790A; SOT-223-3_TabPin2; Manufacturer_Part_Number FZT790A
R4, R5: 1k; R_0805_2012Metric; Manufacturer_Part_Number RT0805BRD071KL
U6: TPS60401; SOT-23-5; Manufacturer_Part_Number TPS60401DBVT
U7: ADP7156ARDZ; SOIC-8-1EP_3.9x4.9mm_P1.27mm_EP2.29x3mm_2; Manufacturer_Part_Number ADP7156ARDZ-3.3-R7

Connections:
+5V: C6.1, C7.1, L1.1, U6.2 (VIN); also elsewhere on the board
+5VA: C18.1, C20.1, C30.1, C32.2, Q1.3 (E), U7.4 (EN), U7.8 (VIN); also elsewhere on the board
+5Vpcm: C10.1, C12.1, L1.2, Q1.2 (C), R4.1; also elsewhere on the board
-5VA: C19.2, C21.1, C29.1, Q2.3 (E); also elsewhere on the board
GND: C6.2, C7.2, C10.2, C11.1, C12.2, C13.2, C14.2, C15.2, C16.2, C17.1, C18.2, C19.1, C20.2, C21.2, C22.1, C23.1, C24.2, C25.2, C26.2, C27.1, C28.1, C29.2, C30.2, C32.1, U6.4 (GND), U7.9 (GND); also elsewhere on the board
unnamed: C14.1, C16.1, Q1.1 (B), R4.2
unnamed: C15.1, C17.2, Q2.1 (B), R5.2
unnamed: C11.2, C13.1, L2.2, Q2.2 (C), R5.1
unnamed: C8.1, C9.1, U6.5 (CP+)
unnamed: C8.2, C9.2, U6.3 (CP-)
unnamed: C27.2, C28.2, L2.1, U6.1 (VOUT)
unnamed: C22.2, U7.3 (BYP)
unnamed: C24.1, U7.5 (REF_SENSE), U7.6 (REF)
unnamed: C23.2, U7.7 (VREG)
VDDA: C25.1, C26.1, U7.1 (VOUT), U7.2 (SENSE); also elsewhere on the board

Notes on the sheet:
Capacitor values with "/1" suffix indicate parts that are required to be class 1 ceramic material

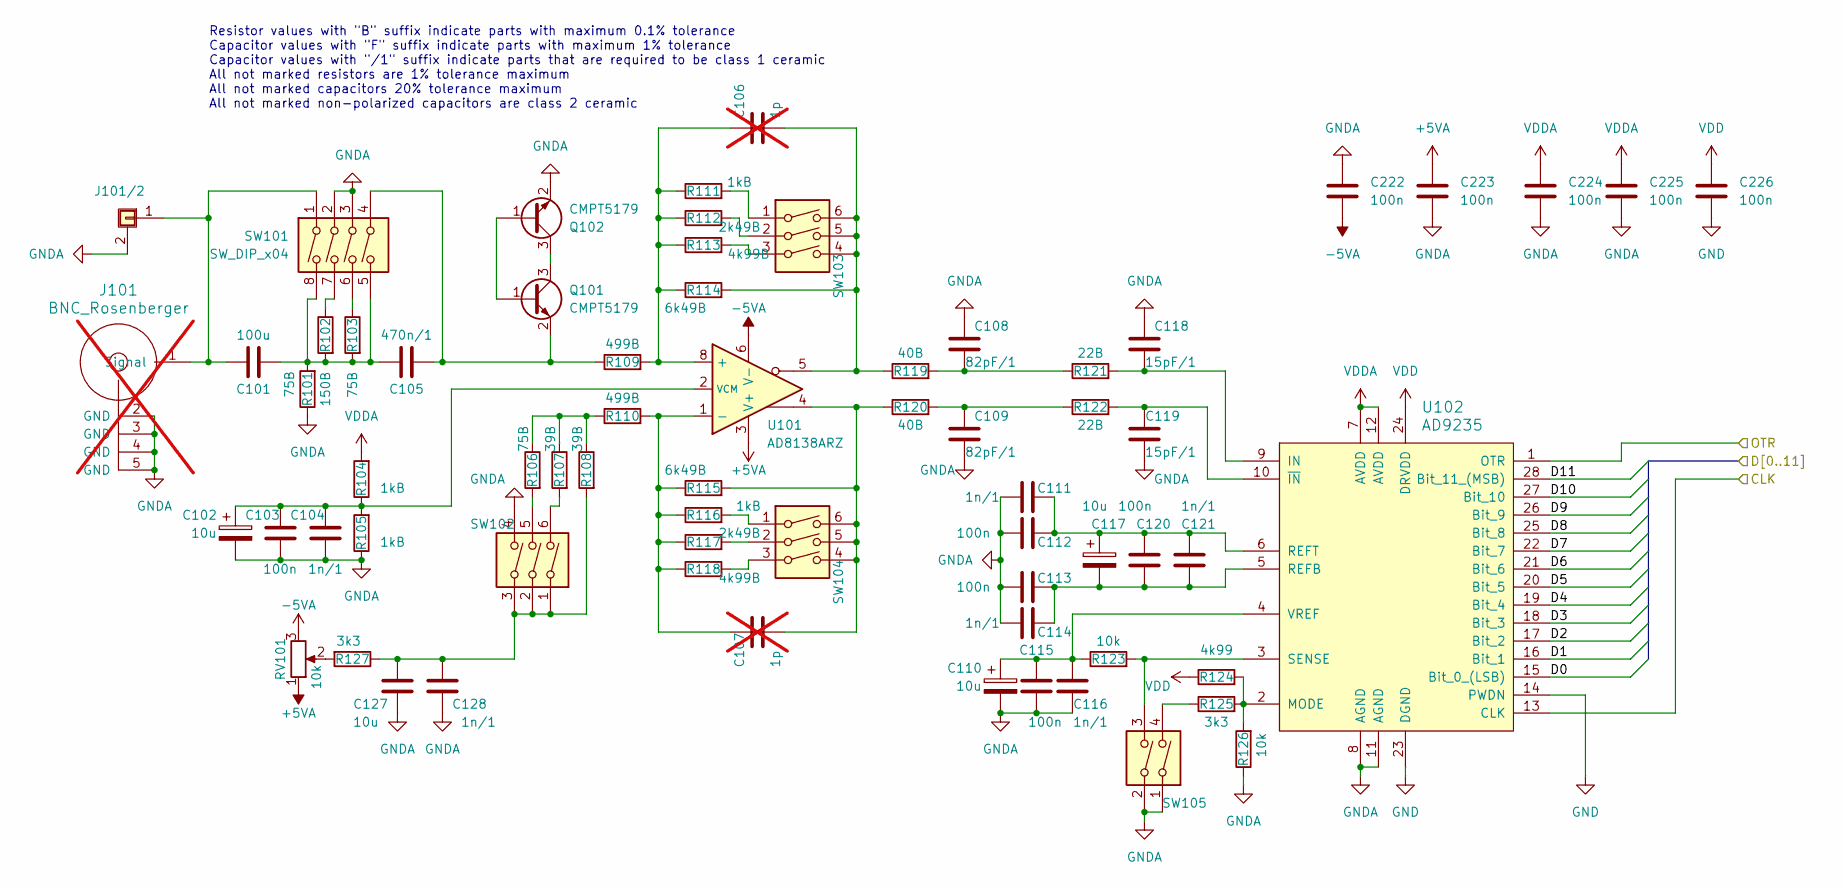
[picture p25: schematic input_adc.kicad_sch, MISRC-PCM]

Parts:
C101: 100u; C_1210_3225Metric; Manufacturer_Part_Number GRM32ER61A107ME20K
C102, C110, C117: 10u; CP_EIA-3528-21_Kemet-B_Pad1.50x2.35mm_HandSolder; Manufacturer_Part_Number T491B106K016AT7280
C103, C112, C113, C115, C120, C222, C223, C224, C225, C226: 100n; C_0805_2012Metric; Manufacturer_Part_Number GRM21BR72A104KAC4L
C104, C111, C114, C116, C121, C128: 1n/1; C_0805_2012Metric; Manufacturer_Part_Number GRM2195C1H102JA01D
C105: 470n/1; C_1206_3216Metric; Manufacturer_Part_Number GRM31C5C1E474JE01L
C106, C107: 1p; C_0805_2012Metric; not fitted
C108, C109: 82pF/1; C_0805_2012Metric; Manufacturer_Part_Number GRM21A5C2D820JW01D
C118, C119: 15pF/1; C_0805_2012Metric; Manufacturer_Part_Number GRM21A5C2D150JW01D
C127: 10u; C_0805_2012Metric; Manufacturer_Part_Number GRM21BR61C106KE15K
J101: BNC_Rosenberger; BNC_Right_Angle-DOSIN-801-0050_5pin; Manufacturer_Part_Number DOSIN-801-0050; not fitted
J101/2: Conn_01x01_Shielded; SMA_Amphenol_901-144_Horizontal; Manufacturer_Part_Number CONSMA002-L-G
Q101, Q102: CMPT5179; SOT-23; Manufacturer_Part_Number CMPT5179 TR PBFREE
R101, R103, R106: 75B; R_0805_2012Metric; Manufacturer_Part_Number RT0805BRD0775RL
R102: 150B; R_0805_2012Metric; Manufacturer_Part_Number RT0805BRD07150RL
R104, R105, R111, R116: 1kB; R_0805_2012Metric; Manufacturer_Part_Number RT0805BRD071KL
R107, R108: 39B; R_0805_2012Metric; Manufacturer_Part_Number RT0805BRD0739RL
R109, R110: 499B; R_0805_2012Metric; Manufacturer_Part_Number RT0805BRD07499RL
R112, R117: 2k49B; R_0805_2012Metric; Manufacturer_Part_Number RT0805BRD072K49L
R113, R118: 4k99B; R_0805_2012Metric; Manufacturer_Part_Number RT0805BRD074K99L
R114, R115: 6k49B; R_0805_2012Metric; Manufacturer_Part_Number RT0805BRD076K49L
R119, R120: 40B; R_0805_2012Metric; Manufacturer_Part_Number RT0805BRD0739R2L
R121, R122: 22B; R_0805_2012Metric; Manufacturer_Part_Number RT0805BRD0722RL
R123, R126: 10k; R_0805_2012Metric; Manufacturer_Part_Number RC0805FR-0710KL
R124: 4k99; R_0805_2012Metric; Manufacturer_Part_Number RC0805FR-074K99L
R125, R127: 3k3; R_0805_2012Metric; Manufacturer_Part_Number RC0805FR-073K3L
RV101: 10k; Potentiometer_Bourns_3266W_Vertical; Manufacturer_Part_Number 3266W-1-103LF
SW101: SW_DIP_x04; SW_DIP_SPSTx04_Slide_6.7x11.72mm_W8.61mm_P2.54mm_LowProfile; Manufacturer_Part_Number IKD0403101
SW102, SW103, SW104: SW_DIP_x03; SW_DIP_SPSTx03_Slide_6.7x9.18mm_W8.61mm_P2.54mm_LowProfile; Manufacturer_Part_Number A6S-3104-H
SW105: SW_DIP_x02; SW_DIP_SPSTx02_Slide_6.7x6.64mm_W8.61mm_P2.54mm_LowProfile; Manufacturer_Part_Number IKD0203101
U101: AD8138ARZ; SO-8_3.9x4.9mm_P1.27mm; Manufacturer_Part_Number AD8138ARZ
U102: AD9235; TSSOP-28_4.4x9.7mm_P0.65mm; Manufacturer_Part_Number AD9235BRUZ-40

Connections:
+5VA: C223.1, RV101.1, U101.3 (V+); also elsewhere on the board
-5VA: C222.2, RV101.3, U101.6 (V-); also elsewhere on the board
/Audio_ADC/SCKI: U102.13 (CLK); also elsewhere on the board
/DA0: U102.15 (Bit_0_(LSB)); also elsewhere on the board
/DA1: U102.16 (Bit_1); also elsewhere on the board
/DA2: U102.17 (Bit_2); also elsewhere on the board
/DA3: U102.18 (Bit_3); also elsewhere on the board
/DA4: U102.19 (Bit_4); also elsewhere on the board
/DA5: U102.20 (Bit_5); also elsewhere on the board
/DA6: U102.21 (Bit_6); also elsewhere on the board
/DA7: U102.22 (Bit_7); also elsewhere on the board
/DA8: U102.25 (Bit_8); also elsewhere on the board
/DA9: U102.26 (Bit_9); also elsewhere on the board
/DA10: U102.27 (Bit_10); also elsewhere on the board
/DA11: U102.28 (Bit_11_(MSB)); also elsewhere on the board
/OTRA: U102.1 (OTR); also elsewhere on the board
GND: C102.2, C103.2, C104.2, C108.1, C109.2, C110.2, C111.1, C112.1, C113.1, C114.1, C115.2, C116.2, C118.1, C119.2, C127.2, C128.2, C222.1, C223.2, C224.2, C225.2, C226.2, J101.2 (GND), J101.3 (GND), J101.4 (GND), J101.5 (GND), J101/2.2 (Shield), Q102.2 (E), R101.1, R105.1, R126.1, SW101.2, SW101.3, SW102.4, SW105.1, SW105.2, U102.8 (AGND), U102.11 (AGND), U102.14 (PWDN), U102.23 (DGND); also elsewhere on the board
unnamed: C101.2, C105.1, R101.2, R102.2, R103.2, SW101.5, SW101.8
unnamed: C106.2, R114.2, R119.1, SW103.4, SW103.5, SW103.6, U101.5
unnamed: C107.2, R115.2, R120.1, SW104.4, SW104.5, SW104.6, U101.4
unnamed: C108.2, R119.2, R121.1
unnamed: C109.1, R120.2, R122.1
unnamed: C127.1, C128.1, R108.2, R127.1, SW102.1, SW102.2, SW102.3
unnamed: C101.1, J101.1 (Signal), J101/2.1, SW101.1
unnamed: Q101.1 (B), Q102.1 (B)
unnamed: Q101.3 (C), Q102.3 (C)
unnamed: C105.2, Q101.2 (E), R109.1, SW101.4
unnamed: R102.1, SW101.7
unnamed: R103.1, SW101.6
unnamed: R106.1, R107.1, R108.1, R110.1
unnamed: R106.2, SW102.5
unnamed: R107.2, SW102.6
unnamed: R111.2, SW103.1
unnamed: R112.2, SW103.2
unnamed: R113.2, SW103.3
unnamed: R116.2, SW104.1
unnamed: R117.2, SW104.2
unnamed: R118.2, SW104.3
unnamed: R125.1, SW105.4
unnamed: R127.2, RV101.2
unnamed: C106.1, R109.2, R111.1, R112.1, R113.1, R114.1, U101.8 (+)
unnamed: C107.1, R110.2, R115.1, R116.1, R117.1, R118.1, U101.1 (-)
unnamed: C102.1, C103.1, C104.1, R104.1, R105.2, U101.2 (VCM)
unnamed: C118.2, R121.2, U102.9 (IN)
unnamed: R124.2, R125.2, R126.2, U102.2 (MODE)
unnamed: C113.2, C114.2, C117.2, C120.2, C121.2, U102.5 (REFB)
unnamed: C111.2, C112.2, C117.1, C120.1, C121.1, U102.6 (REFT)
unnamed: R123.2, SW105.3, U102.3 (SENSE)
unnamed: C110.1, C115.1, C116.1, R123.1, U102.4 (VREF)
unnamed: C119.1, R122.2, U102.10 (~IN)
VDD: C226.1, R124.1, U102.24 (DRVDD); also elsewhere on the board
VDDA: C224.1, C225.1, R104.2, U102.7 (AVDD), U102.12 (AVDD); also elsewhere on the board

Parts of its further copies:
C122, C123, C124, C125, C126, C203, C212, C213, C215, C220: 100n; C_0805_2012Metric; Manufacturer_Part_Number GRM21BR72A104KAC4L
C201: 100u; C_1210_3225Metric; Manufacturer_Part_Number GRM32ER61A107ME20K
C202, C210, C217: 10u; CP_EIA-3528-21_Kemet-B_Pad1.50x2.35mm_HandSolder; Manufacturer_Part_Number T491B106K016AT7280
C204, C211, C214, C216, C221, C228: 1n/1; C_0805_2012Metric; Manufacturer_Part_Number GRM2195C1H102JA01D
C205: 470n/1; C_1206_3216Metric; Manufacturer_Part_Number GRM31C5C1E474JE01L
C206, C207: 1p; C_0805_2012Metric; not fitted
C208, C209: 82pF/1; C_0805_2012Metric; Manufacturer_Part_Number GRM21A5C2D820JW01D
C218, C219: 15pF/1; C_0805_2012Metric; Manufacturer_Part_Number GRM21A5C2D150JW01D
C227: 10u; C_0805_2012Metric; Manufacturer_Part_Number GRM21BR61C106KE15K
J201: BNC_Rosenberger; BNC_Right_Angle-DOSIN-801-0050_5pin; Manufacturer_Part_Number DOSIN-801-0050; not fitted
J201/2: Conn_01x01_Shielded; SMA_Amphenol_901-144_Horizontal; Manufacturer_Part_Number CONSMA002-L-G
Q201, Q202: CMPT5179; SOT-23; Manufacturer_Part_Number CMPT5179 TR PBFREE
R201, R203, R206: 75B; R_0805_2012Metric; Manufacturer_Part_Number RT0805BRD0775RL
R202: 150B; R_0805_2012Metric; Manufacturer_Part_Number RT0805BRD07150RL
R204, R205, R211, R216: 1kB; R_0805_2012Metric; Manufacturer_Part_Number RT0805BRD071KL
R207, R208: 39B; R_0805_2012Metric; Manufacturer_Part_Number RT0805BRD0739RL
R209, R210: 499B; R_0805_2012Metric; Manufacturer_Part_Number RT0805BRD07499RL
R212, R217: 2k49B; R_0805_2012Metric; Manufacturer_Part_Number RT0805BRD072K49L
R213, R218: 4k99B; R_0805_2012Metric; Manufacturer_Part_Number RT0805BRD074K99L
R214, R215: 6k49B; R_0805_2012Metric; Manufacturer_Part_Number RT0805BRD076K49L
R219, R220: 40B; R_0805_2012Metric; Manufacturer_Part_Number RT0805BRD0739R2L
R221, R222: 22B; R_0805_2012Metric; Manufacturer_Part_Number RT0805BRD0722RL
R223, R226: 10k; R_0805_2012Metric; Manufacturer_Part_Number RC0805FR-0710KL
R224: 4k99; R_0805_2012Metric; Manufacturer_Part_Number RC0805FR-074K99L
R225, R228: 3k3; R_0805_2012Metric; Manufacturer_Part_Number RC0805FR-073K3L
RV201: 10k; Potentiometer_Bourns_3266W_Vertical; Manufacturer_Part_Number 3266W-1-103LF
SW201: SW_DIP_x04; SW_DIP_SPSTx04_Slide_6.7x11.72mm_W8.61mm_P2.54mm_LowProfile; Manufacturer_Part_Number IKD0403101
SW202, SW203, SW204: SW_DIP_x03; SW_DIP_SPSTx03_Slide_6.7x9.18mm_W8.61mm_P2.54mm_LowProfile; Manufacturer_Part_Number A6S-3104-H
SW205: SW_DIP_x02; SW_DIP_SPSTx02_Slide_6.7x6.64mm_W8.61mm_P2.54mm_LowProfile; Manufacturer_Part_Number IKD0203101
U201: AD8138ARZ; SO-8_3.9x4.9mm_P1.27mm; Manufacturer_Part_Number AD8138ARZ
U202: AD9235; TSSOP-28_4.4x9.7mm_P0.65mm; Manufacturer_Part_Number AD9235BRUZ-40

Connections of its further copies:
+5VA: C123.1, RV201.1, U201.3 (V+); also elsewhere on the board
-5VA: C122.2, RV201.3, U201.6 (V-); also elsewhere on the board
/Audio_ADC/SCKI: U202.13 (CLK); also elsewhere on the board
/DB0: U202.15 (Bit_0_(LSB)); also elsewhere on the board
/DB1: U202.16 (Bit_1); also elsewhere on the board
/DB2: U202.17 (Bit_2); also elsewhere on the board
/DB3: U202.18 (Bit_3); also elsewhere on the board
/DB4: U202.19 (Bit_4); also elsewhere on the board
/DB5: U202.20 (Bit_5); also elsewhere on the board
/DB6: U202.21 (Bit_6); also elsewhere on the board
/DB7: U202.22 (Bit_7); also elsewhere on the board
/DB8: U202.25 (Bit_8); also elsewhere on the board
/DB9: U202.26 (Bit_9); also elsewhere on the board
/DB10: U202.27 (Bit_10); also elsewhere on the board
/DB11: U202.28 (Bit_11_(MSB)); also elsewhere on the board
/OTRB: U202.1 (OTR); also elsewhere on the board
GND: C122.1, C123.2, C124.2, C125.2, C126.2, C202.2, C203.2, C204.2, C208.1, C209.2, C210.2, C211.1, C212.1, C213.1, C214.1, C215.2, C216.2, C218.1, C219.2, C227.2, C228.2, J201.2 (GND), J201.3 (GND), J201.4 (GND), J201.5 (GND), J201/2.2 (Shield), Q202.2 (E), R201.1, R205.1, R226.1, SW201.2, SW201.3, SW202.4, SW205.1, SW205.2, U202.8 (AGND), U202.11 (AGND), U202.14 (PWDN), U202.23 (DGND); also elsewhere on the board
unnamed: C201.2, C205.1, R201.2, R202.2, R203.2, SW201.5, SW201.8
unnamed: C206.2, R214.2, R219.1, SW203.4, SW203.5, SW203.6, U201.5
unnamed: C207.2, R215.2, R220.1, SW204.4, SW204.5, SW204.6, U201.4
unnamed: C208.2, R219.2, R221.1
unnamed: C209.1, R220.2, R222.1
unnamed: C227.1, C228.1, R208.2, R228.1, SW202.1, SW202.2, SW202.3
unnamed: C201.1, J201.1 (Signal), J201/2.1, SW201.1
unnamed: Q201.1 (B), Q202.1 (B)
unnamed: Q201.3 (C), Q202.3 (C)
unnamed: C205.2, Q201.2 (E), R209.1, SW201.4
unnamed: R202.1, SW201.7
unnamed: R203.1, SW201.6
unnamed: R206.1, R207.1, R208.1, R210.1
unnamed: R206.2, SW202.5
unnamed: R207.2, SW202.6
unnamed: R211.2, SW203.1
unnamed: R212.2, SW203.2
unnamed: R213.2, SW203.3
unnamed: R216.2, SW204.1
unnamed: R217.2, SW204.2
unnamed: R218.2, SW204.3
unnamed: R225.1, SW205.4
unnamed: R228.2, RV201.2
unnamed: C206.1, R209.2, R211.1, R212.1, R213.1, R214.1, U201.8 (+)
unnamed: C207.1, R210.2, R215.1, R216.1, R217.1, R218.1, U201.1 (-)
unnamed: C202.1, C203.1, C204.1, R204.1, R205.2, U201.2 (VCM)
unnamed: C218.2, R221.2, U202.9 (IN)
unnamed: R224.2, R225.2, R226.2, U202.2 (MODE)
unnamed: C213.2, C214.2, C217.2, C220.2, C221.2, U202.5 (REFB)
unnamed: C211.2, C212.2, C217.1, C220.1, C221.1, U202.6 (REFT)
unnamed: R223.2, SW205.3, U202.3 (SENSE)
unnamed: C210.1, C215.1, C216.1, R223.1, U202.4 (VREF)
unnamed: C219.1, R222.2, U202.10 (~IN)
VDD: C126.1, R224.1, U202.24 (DRVDD); also elsewhere on the board
VDDA: C124.1, C125.1, R204.2, U202.7 (AVDD), U202.12 (AVDD); also elsewhere on the board

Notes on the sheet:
Resistor values with "B" suffix indicate parts with maximum 0.1% tolerance Capacitor values with "F" suffix indicate parts with maximum 1% tolerance Capacitor values with "/1" suffix indicate parts that are required to be class 1 ceramic All not marked resistors are 1% tolerance maximum All not mar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

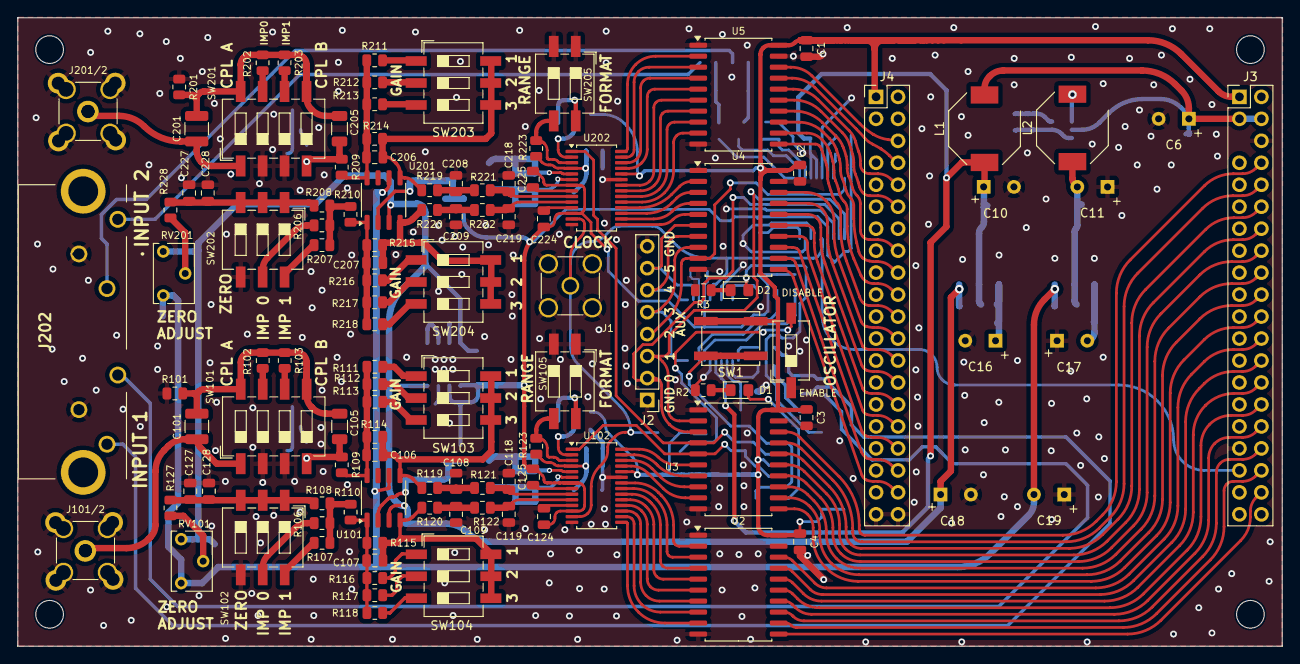
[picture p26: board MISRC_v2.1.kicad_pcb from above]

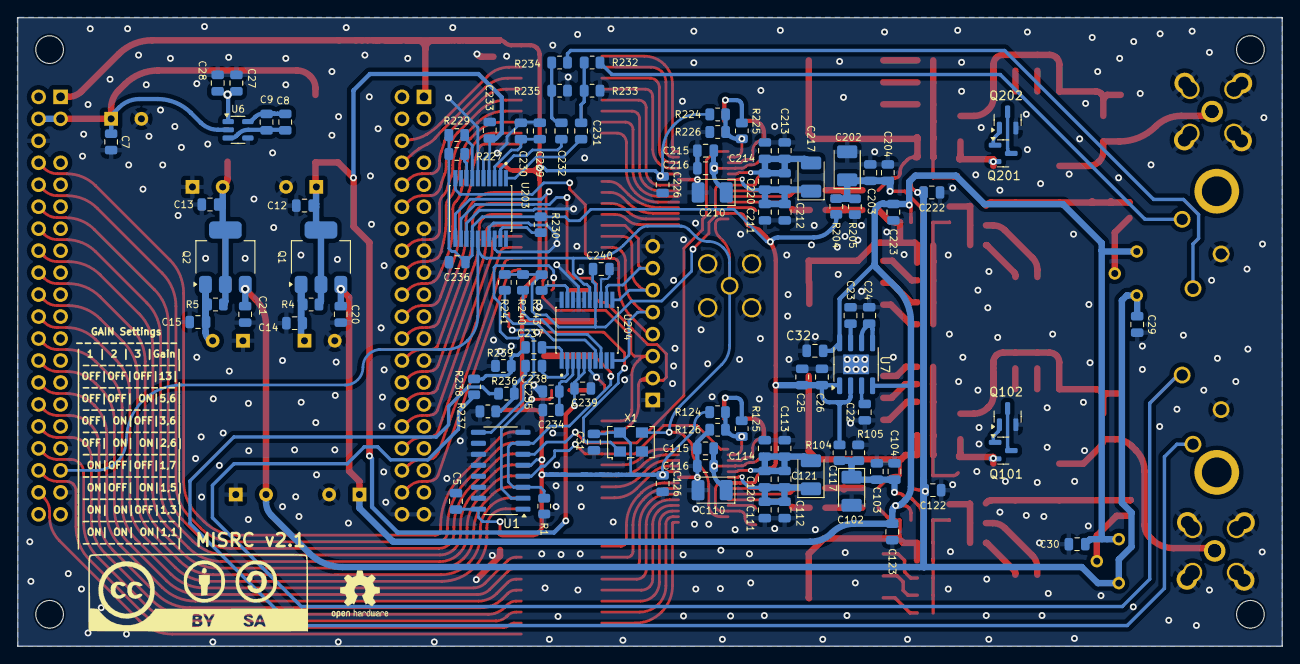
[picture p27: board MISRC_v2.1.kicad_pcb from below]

Board: 2 copper layers, 146.2 x 72.6 mm, 224 parts (104 on the bottom side), 173 nets.

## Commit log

2024-05-23 Replace BNC connector
    Replace BNC connector and change PCB size to "original" MISRC
    [BOM_MISRC_v2.1.xlsx, DOSIN-BNC_F102-243.stp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]
2024-05-23 Update silkscreen
    Update bottom side silkscreen
    [MISRC_v2.1-B_Cu.gbl, MISRC_v2.1-B_Mask.gbs, MISRC_v2.1-B_Paste.gbp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]

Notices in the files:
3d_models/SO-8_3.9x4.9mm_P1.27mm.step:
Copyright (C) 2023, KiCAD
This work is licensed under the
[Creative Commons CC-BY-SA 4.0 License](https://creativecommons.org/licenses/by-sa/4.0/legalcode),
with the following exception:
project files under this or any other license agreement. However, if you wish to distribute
